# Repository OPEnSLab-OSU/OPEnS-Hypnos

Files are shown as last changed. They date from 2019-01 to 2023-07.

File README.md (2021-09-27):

# OpenS-Hypnos
Power Control Board for microcontroller projects, designed at OPEnS Lab OSU.

Go to [Hypnos Wiki](https://github.com/OPEnSLab-OSU/OPEnS-Lab-Home/wiki/Hypnos) for more info and build guide.

<p align="center">
    
 
</p>

### Pinout
Hypnos V3.3 Pinout

### Description
The OPEnS-Hypnos board is a simple, low-cost circuit board that can be attached to an Adafruit Feather M0 microcontroller and a DS3231 real-time clock breakout board to enable shutting off power to the microcontroller until a timed or sensed event wakes it up.
In the early time of development, the Feather needs to be shut down completely due to the inefficient  deep sleep firmware.
A circuit was designed to keep the state of the system, and a real-time clock can change the state and wake everything back up.
After Adafruit released new firmware for Feather M0 that allows microamp sleep current, complete shutdown of the Feather seem unnecessary.
However, during deep sleep, the 3v3 volt regulator is still providing power to other peripherals. 
MOSFET circuitry is introduced in HYPNOS to cut down power to peripherals. Additional RTC and microSD for accurate timekeeping and data logging.

* `Hypnos V2.x` Power + RTC + microSD with FeatherWing footprint. Allow control on 3.3V and VUSB rail. Using MOSFET circuit and Feather deep sleep
* `Hypnos V3.x` Upgraded from regular Hypnos. Can control one more rail of higher voltage (9-24V) at max 2.0 A continuous
* `Hypnos V3.3.lbr` Eagle library that has all of the components the Hypnos contains such as the push button, MOSFET footprints, Feather pinout, etc. 

### Specification
* Controlled 3v3 Rail (0.4 A continuous) and 5V Rail (0.5 A continuous from USB)
* [RTC DS3231](https://datasheets.maximintegrated.com/en/ds/DS3231.pdf) with TCXO
* Back up power CR1220 for RTC
* Micro SD slot

### Pinout for Feather M0
* RTC INTerrupt pin: GPIO 12
* 3.3V control pin: GPIO 5
* 5V control pin: GPIO 6
* SD chip select: GPIO 11

### How to use this board
<details>
<summary>Show more</summary>

### Important ! 3v3 RAIL ! 

Any I2C device behind [Adafruit I2C Multiplexer](https://www.adafruit.com/product/2717) does not need to be powered. We have tested the system with the Multiplexer turn off without the I2C line hanging.

Remember to power the 3.3Rail before initializing/communicating with uSD card, RTC, and I2C devices.

### Which rail to which?
<p align="center">

</p>

* **Feather Rail:** connects directly to your Feather. Anything connected to this rail will have their power constantly on and only turn off in **Shipment Mode**. Power Control will not work on this rail.

* **Sensor/Power Rail:** connects directly to your sensor board which you wish to turn the power on/off. The 5VUSB pin and 3V pin are controlled within the rail. Digital and Analog pins on this rail connect directly to the Feather. Extra 3V|5V with LEDs are for an external plug for prototyping.

### To control the power rails:



* **3v3 rail**: Set `PIN 5` of the Feather to **LOW** for closed circuit (conduct), otherwise, the pin is pulled HIGH for open circuit (not conduct).

* **5V rail**: Set `PIN 6` to **HIGH** for closed circuit (conduct), the PIN is pulled LOW for open circuit

* **+V rail**: This pin shares control with the 5V rail. Set `PIN 6` to **HIGH** for closed circuit (conduct), the PIN is pulled LOW for open circuit

**SD card:** Chip Select `PIN 11`, **required** 3.3Rail power, normal SPI communication

**RTC DS3231:** INT-errupt `PIN 12`, **required** 3.3Rail power, I2C pull up attached to 3.3Rail

**Note:** If you need a GPIO pin **AND** you are not using one of the 3V or 5V rails, you are able to free the GPIO pin for use by cutting the trace of the rail that is not used. 

### Shipment Mode
Short the `GND` and `EN` will turn off the 3.3V regulator temporarily. The male header + Jumper cap is a great combination. Once the jumper cap is removed, the Feather will boot up normally and resume operation.

</details>

### Note
* 5Vrail can go up to 1.2A if external 5V is connected directly to **Feather USB pin**
* The LEDs are low power (rated at 2mA instead of 20mA)
* I2C line pull up is attached to 3VRail

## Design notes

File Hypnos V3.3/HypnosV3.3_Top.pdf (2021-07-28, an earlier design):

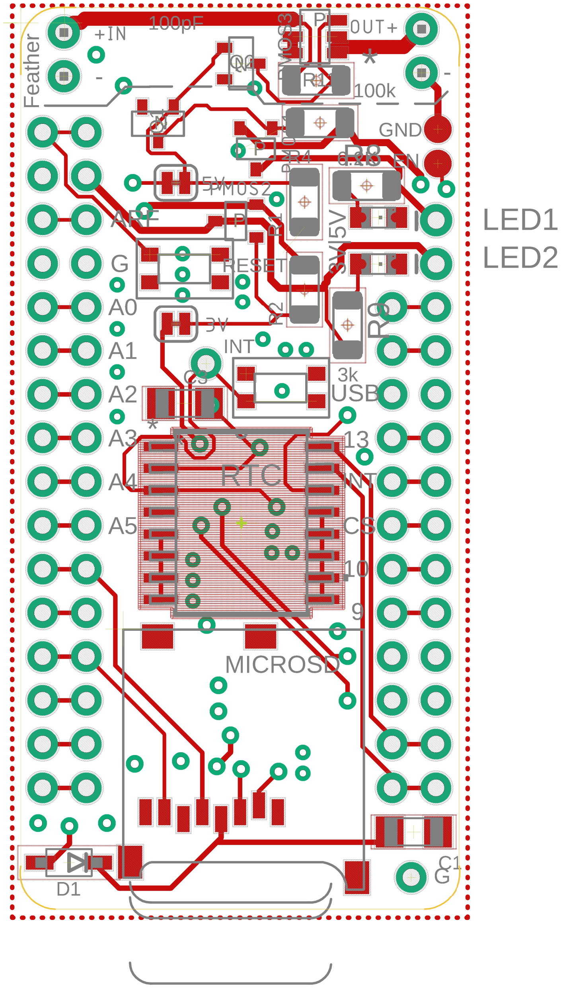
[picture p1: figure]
LED1 LED2

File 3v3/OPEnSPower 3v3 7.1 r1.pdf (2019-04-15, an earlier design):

OPEnS Power 3v3
Board Revision: 7.1
Document Revision: 1
Date: April 15, 2018
Author: Mitch Nelke

## Abstract

The OPEnS Power board is a simple, low cost circuit board that can be attached to an Adafruit Feather M0 microcontroller and a DS3231 real time clock breakout board to enable shutting off power to the microcontroller until a timed or sensed event wakes it up. The powered-down current draw of the system, minus any external circuits attached to the battery, is reduced to the order of 100 microAmps*. The board operates by applying two interrupt signals, one high-true and one low-true, to a flip flop integrated circuit to wake the device up. The flip flop latches the enable pin of the Feather's 3.3V regulator on or off. A digital output pin on the Feather is used to set the flip flop to latch the regulator off.

The OPEnS Power board is best suited for projects that require operating-time that are greatly shorter than their standby times. The lowest possible standby current achievable on the M0 without the OPEnS Power board is just under 1000 uA. By using the OPEnS Power board and assuming the on-time is far greater than the standby time, the battery life of the Feather M0 project can be increased by a factor of 10.

* Based on previous iterations of OPEnS Power. New iteration should be tested for exact value.

## Characteristics

Characteristic | Condition | Min | Max | Units
VCC | | TBD | 5.5 | V
CP Logic HIGH | VCC = 2.3-5.5V | 0.7 VCC | | V
CP Logic LOW | VCC = 2.3-5.5V | | 0.3 VCC | V
RTC_INT Logic HIGH | VCC = 4.2V | 0.7 VCC | | V
RTC_INT Logic LOW | VCC = 4.2V | | 0.3 VCC
INT_2 Logic HIGH | VCC = 4.2V | 2.5 | | V
INT_2 Logic LOW | VCC = 4.2V | | 1 | V
3v3 Reg EN Output Logic HIGH | VCC = 4.2V | TBD | | V
3v3 Reg EN Output Logic LOW | VCC = 4.2V | | TBD | V
Quiescent Current* | CP = LOW | | TBD | uA

*Does not include quiescent current from circuits using battery voltage on Feather M0 board.

## Theory of Operation

The OPEnS Power board uses a flip flop integrated circuit (IC) to turn on and off the 3.3V regulator on the Feather M0. The flip flop IC’s input pin D is permanently attached to the battery source. The logic state of the input is copied to the output, Q, when the clock pulse (CP) pin receives a rising edge from the M0. When CP receives a falling edge, nothing happens. The flip flop is powered from the battery and decoupled with a 100nF capacitor. The battery voltage pulls up the C-bar input through a 10k resistor. The C-bar input latches the Q output to ground whenever it is pulled low. The output remains low, ignoring any CP rising edges, until C-bar is pulled high.

The low-true interrupt meant to be connected to the DS3231 Real Time Clock’s (RTC) alarm output is directly tied to the C-bar pin. A second interrupt pin, INT_2, is high-true and is connected to the gate of an N-channel MOSFET. The MOSFET’s source pin is tied to ground and its drain pin is connected to C-bar so that a high voltage on the INT_2 signal will pull C-bar low. It is possible to read the state of C-bar through GPIO_READ by using input_pullup() in the Arduino IDE. A diode between this pin and C-bar protects the state of C-bar when the M0 is powered off.

The Q output is a low-true signal but the 3.3V Regulator’s Enable pin is high-true. The Q output is connected to the gate of a P-channel MOSFET to invert its logic. When Q is high, the source and drain of the MOSFET are essentially disconnected and the regulator enable pin is tied to ground. When Q is low, the source and drain are essentially shorted and the regulator enable pin receives the battery voltage through a 500 ohm resistor.

## Application

Connections
The application of the OPEnSPower 3.3V board is simple. An Adafruit Feather M0 board should be connected to the board. The default Read and CP pins are A4 and A5, respectively, if their jumpers are soldered. If their jumpers are not soldered, different pins can be chosen by soldering a wire to the flip-flop side of each jumper. The current draw of these signals is very small and so wire-wrap is acceptable.

A 3.7V LiPo battery should be connected to the Feather’s battery receptacle. The battery source is connected to the OPEnSPower board through the Feather’s BAT pin.

Finally, the RTC_INT pin should be connected to a low-true interrupt signal to wake up the device. This is usually the DS3231’s SQW pin, and an alarm should be set before shutting the

M0 down. A high-true interrupt signal can be connected to INT_2. Generally, such a device would have its own power supply and its ground should be connected to the M0 and OPEnSPower ground.

Software
Assuming the DS3231’s SQW pin is connected to the RTC_INT (“INT-“) pin of the OPEnSPower board, the control scheme is very simple.
1. Wake up the device if it is off by shorting the RTC_INT pin to ground.
2. Read volatile variables from Flash storage or wherever they are stored between power cycles.
3. Perform desired functions.
4. Save volatile variables to persistent storage location.
5. Reset RTC alarm and set new alarm time for the system to wake up.
6. Shut the device off by pulling GPIO_CP high on the M0.

## Schematic

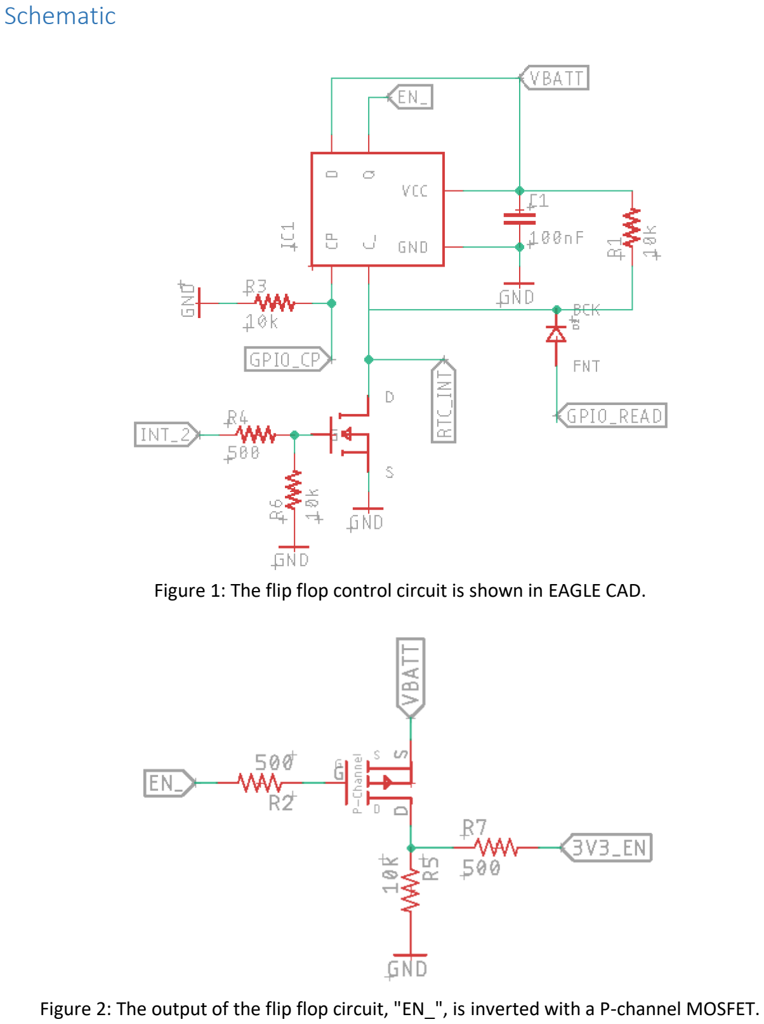
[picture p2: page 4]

Figure 1: The flip flop control circuit is shown in EAGLE CAD.

Figure 2: The output of the flip flop circuit, "EN_", is inverted with a P-channel MOSFET.

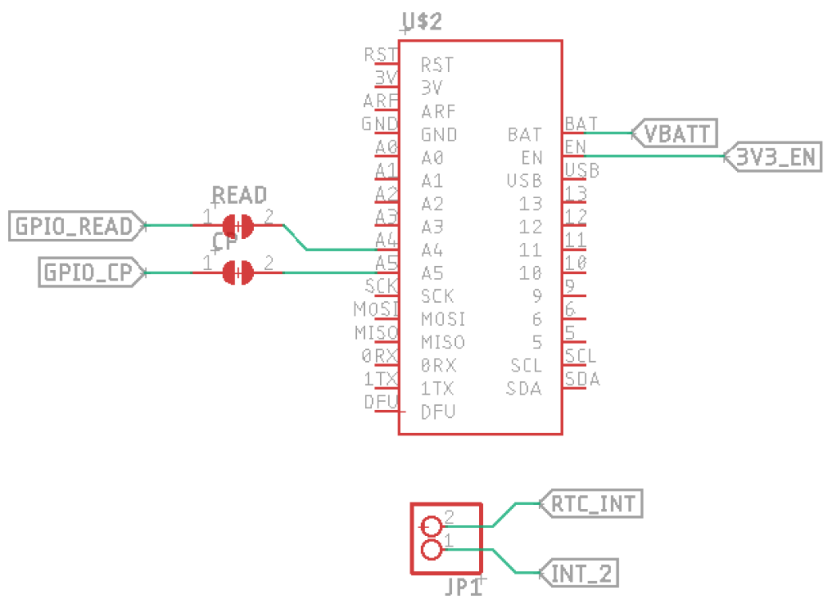
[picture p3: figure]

Figure 3: The Feather M0 is connected to READ, CP, VBATT, and 3v3_EN.

## Board Image From OSHPark

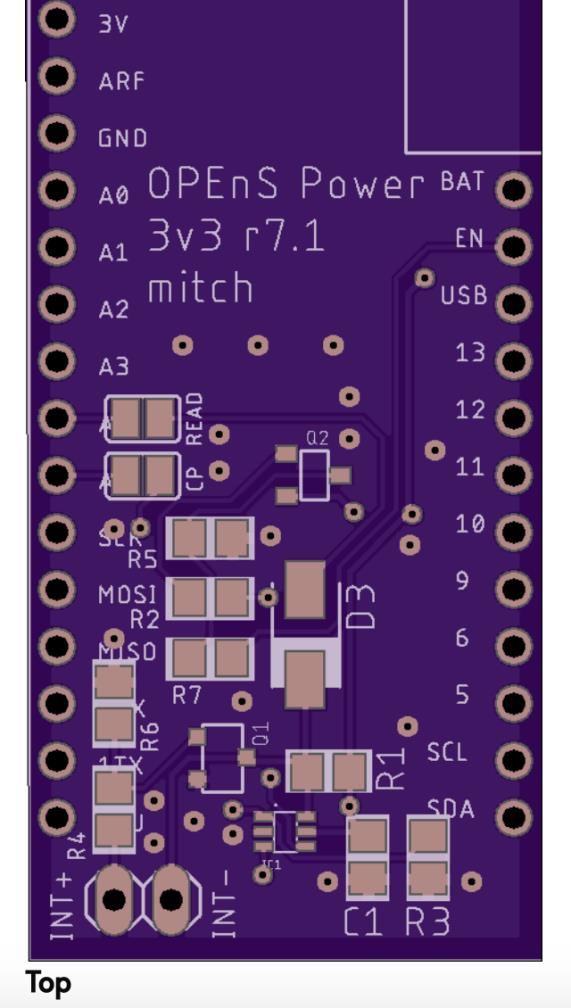
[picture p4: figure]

Figure 4: Top view of board after submitting to OSHPark for printing. Before operating, the CP and READ jumpers should be bridged with solder.

## Bill of Materials

Item | Value / ID | Footprint | Quantity | Board ID | Source
| | | | | (Hyperlink)
Resistor | 500 Ohm | 0805 | 3 | R2, R4, R7 | Digikey (https://www.digikey.com/product-detail/en/stackpole-electronics-inc/RNCP0805FTD499R/RNCP0805FTD499RCT-ND/2240560)
Resistor | 10 kOhm | 0805 | 4 | R1, R3, R5,
| | | | R6 | Digikey (https://www.digikey.com/product-detail/en/stackpole-electronics-inc/RNCF0805DTE10K0/RNCF0805DTE10K0CT-ND/2687083)
Capacitor | 100 nF | 0805 | 1 | C1 | Digikey (https://www.digikey.com/product-detail/en/yageo/CC0805KRX7R8BB104/311-1141-1-ND/303051)
MOSFET, N-
Channel | 2N7002-7-F | SOT-23-3 | 1 | Q1 | Digikey (https://www.digikey.com/product-detail/en/diodes-incorporated/2N7002-7-F/2N7002-FDICT-ND/717800)
MOSFET, P- Channel | SSM3J3228R | SOT-23-3 | 1 | Q2 | Digikey (https://www.digikey.com/product-detail/en/diodes-incorporated/BSS84-7-F/BSS84-FDICT-ND/717844)
Diode | APD340VRTR-
| G1 | DO-214AC | 1 | D1 | Digikey (https://www.digikey.com/product-detail/en/diodes-incorporated/APD340VRTR-G1/APD340VRTR-G1DICT-ND/5453146)
Flip Flop | NC7SZ175 | SC70/SC88 | 1 | IC1 | Digikey (https://www.digikey.com/product-detail/en/on-semiconductor/NC7SZ175P6X/NC7SZ175P6XCT-ND/673397)

## Future Development Suggestions

If a more efficient, simpler, or cheaper board is desired in the future, there are several routes that could be investigated. To start, the flip flop circuit could be redone or a new flip flop could be chosen so that the interrupt vectors act to pull the output of the flip flop high rather than low. This would remove the requirement of the inverting P-channel MOSFET circuit. For maximum efficiency, it would be desirable to fully analyze the Feather M0's 3.3V Regulator characteristics and adjust the interrupt vectors' rise and fall times and phase so that a flip flop IC is not necessary at all. It is worth noting that the internal leaking current of a LiPo battery is on the order of 100 uA, so reducing the quiescent current below this level has diminishing effects on overall battery life.

It should also be noted that this board does not disconnect the battery from the system during shutoff. There is a voltage divider on the Feather M0 feeding into an input pin to allow it to read the battery voltage, but the current draw of this divider is about 42 uA. The resistors can be removed to further reduce the system's standby current. The standby current of the 3.3V regulator when EN is low is on the order of 8 uA and so it is not useful to work around it.

## Reference Documents

Datasheet of Flip Flop: https://www.onsemi.com/pub/Collateral/NC7SZ175-D.PDF

Datasheet of Feather M0 3.3V Regulator: http://www.mouser.com/ds/2/146/SPX3819_DS_R200_082312-17072.pdf

Boards for OPEnS Lab are generally ordered from the 2-layer PCB Pool of OSHPark: https://oshpark.com/

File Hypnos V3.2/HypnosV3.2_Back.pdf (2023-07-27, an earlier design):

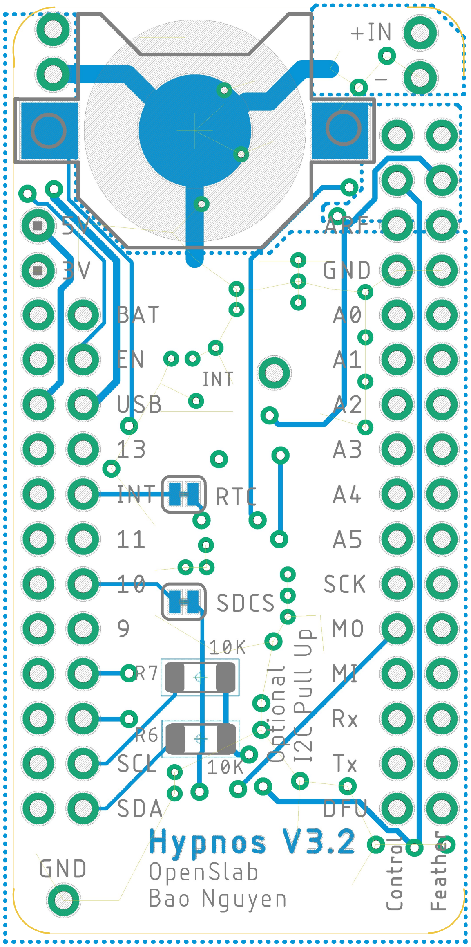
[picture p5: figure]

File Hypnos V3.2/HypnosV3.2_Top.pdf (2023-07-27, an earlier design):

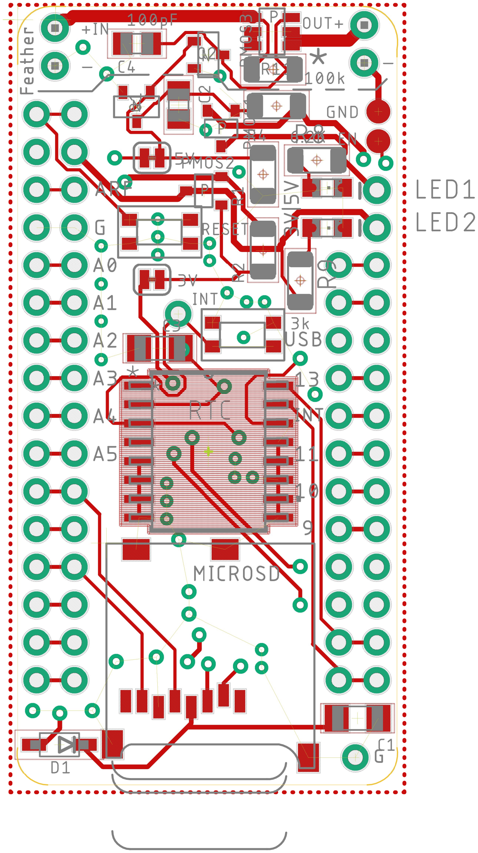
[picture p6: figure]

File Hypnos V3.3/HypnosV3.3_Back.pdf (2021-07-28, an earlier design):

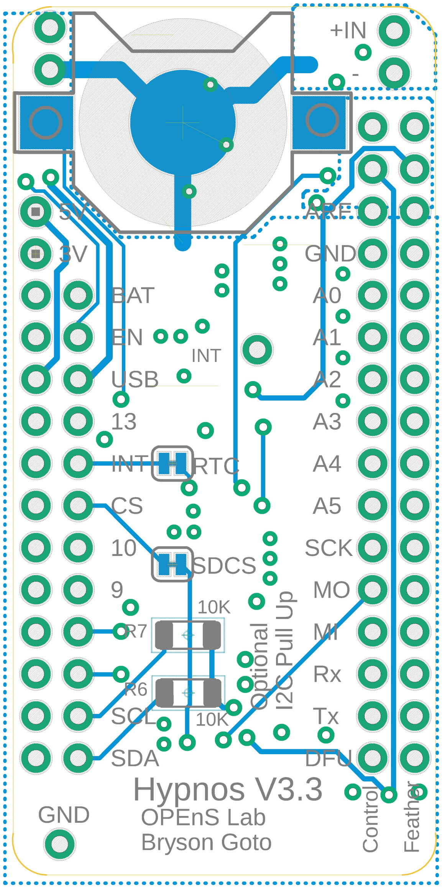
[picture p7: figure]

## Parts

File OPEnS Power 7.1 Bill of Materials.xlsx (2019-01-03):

Component | Board ID | Component ID | Source | Qty
Switching Regulator | IC2 | LM2575Sx-5.0/NOPBCT-ND | Digikey (https://www.digikey.com/product-detail/en/texas-instruments/LM2575SX-5.0-NOPB/LM2575SX-5.0-NOPBCT-ND/3440104) | 1
Barrel Jack | 12V_IN | CP-002BHPJCT-ND | Digikey (https://www.digikey.com/product-detail/en/cui-inc/PJ-002BH-SMT-TR/CP-002BHPJCT-ND/669694) | 1
Capacitor 100 uF | C12 | PCE3867CT-N | Digikey (https://www.digikey.com/product-detail/en/panasonic-electronic-components/EEE-1AA101WR/PCE3867CT-ND/766243) | 1
Capacitor 470 uF | C13 | 493-2181-1-ND | Digikey (https://www.digikey.com/product-detail/en/nichicon/UWT1C471MNL1GS/493-2181-1-ND/590156) | 1
Capacitor 100 nF | C1 | 1276-1007-1-ND | Digikey (https://www.digikey.com/product-detail/en/samsung-electro-mechanics/CL21F104ZBCNNNC/1276-1007-1-ND/3889093) | 1
Inductor 470 uH | L1 | 732-1690-1-ND | Digikey (https://www.digikey.com/product-detail/en/wurth-electronics-inc/744770247/732-1690-1-ND/1994270) | 1
Diode General Thru | D4 | 641-1310-1-ND | Digikey (https://www.digikey.com/product-detail/en/comchip-technology/1N4001-G/641-1310-1-ND/1979675) | 1
Resistor 10k | R3, R4 | RR12P10.0KDCT-ND | Digikey (https://www.digikey.com/product-detail/en/stackpole-electronics-inc/CF18JT10K0/CF18JT10K0CT-ND/2022766) | 2
Resistor 130k | R1 | 311-130KCRCT-ND | Digikey (https://www.digikey.com/product-detail/en/yageo/RC0805FR-07130KL/311-130KCRCT-ND/730537) | 1
Resistor 300k | R2 | RR12P300KDCT-ND | Digikey (https://www.digikey.com/product-detail/en/susumu/RR1220P-304-D/RR12P300KDCT-ND/432889) | 1
Diode General SMD | D2, D3 | S1A-FDICT-ND | Digikey (https://www.digikey.com/product-detail/en/diodes-incorporated/S1A-13-F/S1A-FDICT-ND/750031) | 2
Flip Flop | IC1 | 296-16998-1-ND | Digikey (https://www.digikey.com/product-detail/en/texas-instruments/SN74LVC1G175DCKR/296-16998-1-ND/656525) | 1
MOSFET N-Type | Q1 | 2N7002-TPMSCT-ND | Digikey (https://www.digikey.com/product-detail/en/micro-commercial-co/2N7002-TP/2N7002-TPMSCT-ND/1960099) | 1
Diode - Zener 5.1V | D1 | BZD27C4V3P-E3-08GICT-ND | Digikey (https://www.digikey.com/product-detail/en/vishay-semiconductor-diodes-division/BZD27C4V3P-E3-08/BZD27C4V3P-E3-08GICT-ND/6680647) | 1

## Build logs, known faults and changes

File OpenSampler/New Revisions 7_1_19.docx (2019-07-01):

Change with James:

- Replace RTC capacitor with battery since charging capacitor would take sometimes, as well as the voltage are only usable in a certain range.

Charging with 4.2- 0.7 = 3.5 volt is still higher than the voltage the RTC can handle which is 3V.

- Utilized Voltage Divider on 2nd Inverter node and V_Latch node to determine NMOS resistance value for proper current.

Change by Bao:

- Reposition the side rail so it fit on the breadboard - Multiple of 2.54mm spacing

- Replace test pins with continuous header holes

- Resize and rearrange printed letters so they would print nicely

- Add letters for test pins

- Rewire signal rail and power rail for easy installation

- Move LED from bottom layer to front

Suggested change from Bao:

- Remove 1nF capacitor due protect the RTC. Current spike is allowed for the RTC INT => can blow the RTC

- The board when overrided to stay awake, the latch will pulled to GND. The shutdown pin is only have 1 resistor and 1 diode away from a feather pin.

This will cause over current sink from the feather pin if it tries to sent shutdown signal.

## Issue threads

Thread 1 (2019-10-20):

Measuring SD card current

kamocat, 2019-10-20:
Currently there isn't a way of measuring the current consumption of the SD card separate from the reset of the system.
A simple 1-ohm high-side sense resistor would allow measurement, requiring minimal board space. Optionally, this signal could be wired back and monitored by the Feather.

**Benefits of measuring the SD card current:**
* Compare current draw of different SD cards (brand, capacity, age, etc)
* Ensure that a write operation is complete before shutting off power (to avoid data corruption)
* Compare power consumption of cached vs uncached writes

nguyenb5, 2019-10-29:
The issue has been viewed. What do you think is the best way to read the voltage drop across the resistor, just an analog pin? Do you think that the drop through the MOSfet also effect the reading?

kamocat, 2019-10-31:
Maybe you're right, that no-one is going to measure the current from the Feather.
I found a different issue that complicates this, though. My SD card seems to be feeding power back into the 3.3V rail through the SPI bus. I haven't tried a current test (because I don't wish to break the SD card), but it's enough to turn on the LED.
I think it's getting the power either from MOSI or SCK, because setting CS low didn't completely fix it. Maybe a schottkey diode would do it?
I guess the simple answer is that if I want the feather to sleep, I need to disable all the output drivers first.

nguyenb5, 2019-11-01:
Did you have the SD card inserted then started the SPI protocol? I am trying to replicate the issue on my end for troubleshooting.

kamocat, 2019-11-13:
Closing this issue. I changed my mind about the current consumption, I can put a sense resistor on the 3v3 rail if I want.

Closed 2019-11-13.

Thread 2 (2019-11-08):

Current leak from MISO, MOSI, CS ?

nguyenb5, 2019-11-08:
When the SD card is initialized and the 3V power rail is disconnected, the 3VRAIL seem to still turn on (LED lit up).

Need to probe voltage at MISO, MOSI, CLK, SD to check if there is any current flowing backward to the 3Vrail when the 3V control pin is not activated.

Issue seen from Sitka+ SapFlow.

kamocat, 2019-11-13:
Yes, you need to start the SPI protocol, or at configure some of those pins as outputs.

kamocat, 2019-11-13:
Additionally, I would recommend moving the I2C pull-ups to the unswitched 3V3 rail, as they also are dimly powering the LED when pull-ups on the Feather are enabled. This would put them on the same rail as the RTC.

nguyenb5, 2019-11-14:
Hi Marshal, I read over your message but did not understand well the issue with the I2C Pull-up resistors.

I have not talked to the Loom team but please let us know if you found a way to fix this in software. From Max's testing, the current is leaking from all of the SPI pin including CS. I will start implementing the diode fix to future update, but I do want to sit down and have a chat with you for the board schematic before we purchase anything.

kamocat, 2019-11-14:
My bad. I misread the schematic, and thought the pullups connected to 3VRail, not 3V3.

kamocat, 2019-11-14:
Setting the pins as inputs seems to work pretty well.
Just make sure you don't set pin 22 as an output.
Here's an example sketch.
https://gist.github.com/kamocat/b4cf9f0ccbd765f78a6d7390d2da2fe8

nguyenb5, 2019-11-21:
Hi Marshal,

Where you able to use this code with Loom?

kamocat, 2019-11-23:
I haven't tried it with Loom, but I don't see any reason why it wouldn't work.

nguyenb5, 2020-01-18:
[Updates](https://github.com/OPEnSLab-OSU/OPEnS-Lab-Home/wiki/Hypnos-Updates). A diode has been place between 3v3Rail and the VCC of the SDcard that reduce leakage current down to 1.9uA.

Diode: [SM5817PL-TP](https://www.digikey.com/product-detail/en/micro-commercial-co/SM5817PL-TP/SM5817PL-TPMSCT-ND/1793410)

Closed 2020-01-18.

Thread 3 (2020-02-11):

I2C line broke for non-powered external sensor

nguyenb5, 2020-02-11:
With the code test for the RTC DS3231, the I2C communication would fail if there is external I2C sensor that connected to SDA and SCL without being power (disconnected Vcc and GND).

nguyenb5, 2020-02-12:
Phantom Power : https://forum.arduino.cc/index.php?topic=642971.0

udellc, 2020-02-13:
Is there a way to disconnect only the VCC line to the sensor, but keeping it grounded? Would that fix the issue?

udellc, 2020-02-17:
It looks like isolating the i2c bus will be necessary. This one is an updated version of the one recommended on the discussion board posted above:
http://www.ti.com/product/TCA4311A
I think we may need to make a new version of our Loom i2c shield, which includes an option to populate the TCA9548 i2c MUX but also with the TCA4311A buffer on the shield's i2c input.
The shield should also include an i2c pass through after the buffer, for being able to use isolated i2c devices without the MUX if desired.

nguyenb5, 2020-02-18:
This issue is not resolved yet. The buffer require some more space that the current Hypnos V2 does not have. Requested feature will be postponed to later version.

nguyenb5, 2020-03-24:
For now, the system is still usable if the all of the I2C devices are powered before communicating with the RTC. The I2C Multiplexer can be not powered, and system will still work.

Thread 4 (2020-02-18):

Current leak from I2C line

nguyenb5, 2020-02-18:
[Hypnos V2.zip](https://github.com/OPEnSLab-OSU/OPEnS-Hypnos/files/4216852/Hypnos.V2.zip)
The current I2C line is pulled up to +3V. Sensors which share the pin will use the power from the I2C line when they are being shut off. For the MMA8451 board, I was getting leakage of 170uA for SCL and 70uA for SDA when the device is off and no communication.

kamocat, 2020-02-23:
That's strange. I thought the pull-ups were tied to the switched 3V3 rail.

nguyenb5, 2020-03-01:
not in the current Hypnos V2. We fixed it in Hypnos V2.1.

Closed 2020-03-24.

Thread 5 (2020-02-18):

Periodic Sleep/Wake Hangs After ~20min

prototypicalpro, 2020-02-18:
I am experience hanging when using the Hypons board with the Loom Sleep example (https://github.com/OPEnSLab-OSU/Loom/tree/master/examples/Lab%20Examples/Hypnos_SD_Sleep). I have found that consistently after about 20 minutes of continuous sleep/wakeup operation, the board will freeze just after waking up, and will remain unresponsive until it is reset.

I am using an Adafruit Feather M0 WiFi with the new and old hypnos versions. I used the same RTC battery for both, which measured 2.913V.  Interestingly, an RTC breakout with an adalogger did not experience the same symptoms, despite also using sleep functionality (The RTC battery on the breakout measured slightly higher at 3.012V, but seemed too little of a difference to cause issues). Frustratingly, I also found this issue only happens when using sleep functionality: in other words I am unable to reproduce the issue after removing the "Loom.SleepManager().sleep()" line.

prototypicalpro, 2020-02-18:
All of a sudden I'm having issues replicating the problem: I ran the same setup of both new and old hypnos over the weekend with no issue. Since my previous tests were Tuesday-Thursday, @udellc suggested the issue might be related to the RTC being set to that time, however I tested setting RTC to last Thursday and was still unable to replicate the issue.

I'm stumped as to what to test next. Any ideas @nguyenb5 ?

nguyenb5, 2020-07-03:
I still not yet heard any other report about the board freeze from walking up. There will be another batch for Hypnos V3.2 that have been tested by two other projects. Please let me know if this happen again. For now, I think you should wake up, turn on the 3V rail and delay for at least 10ms for the I2C pull up.

udellc, 2020-07-03:
FYI

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

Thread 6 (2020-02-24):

Finalize Board for Build Party?

udellc, 2020-02-24:
Are these issues for V2 still a problem? What needs to be fixed to finalize the design so we can have the next build party?
Thanks,
Chet

nguyenb5, 2020-04-06:
Hi Dr.Chet, changes has been implemented for the V2 and V3. Ready for testing

Closed 2020-04-17.

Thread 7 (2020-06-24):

Always connect 3.3V and 5V control solder pad

nguyenb5, 2020-06-24:
Currently, to have the control power for the 3.3V rail and 5V rail, user would have to solder bridge pads. Since this is a normal feature, it should be activated out of the box.

Newer version of the PCB should have this to reduce solder time and chances that one might forget.

nguyenb5, 2020-07-03:
Fixed in Hypnos V3.2 and V2.2

Closed 2020-07-03.

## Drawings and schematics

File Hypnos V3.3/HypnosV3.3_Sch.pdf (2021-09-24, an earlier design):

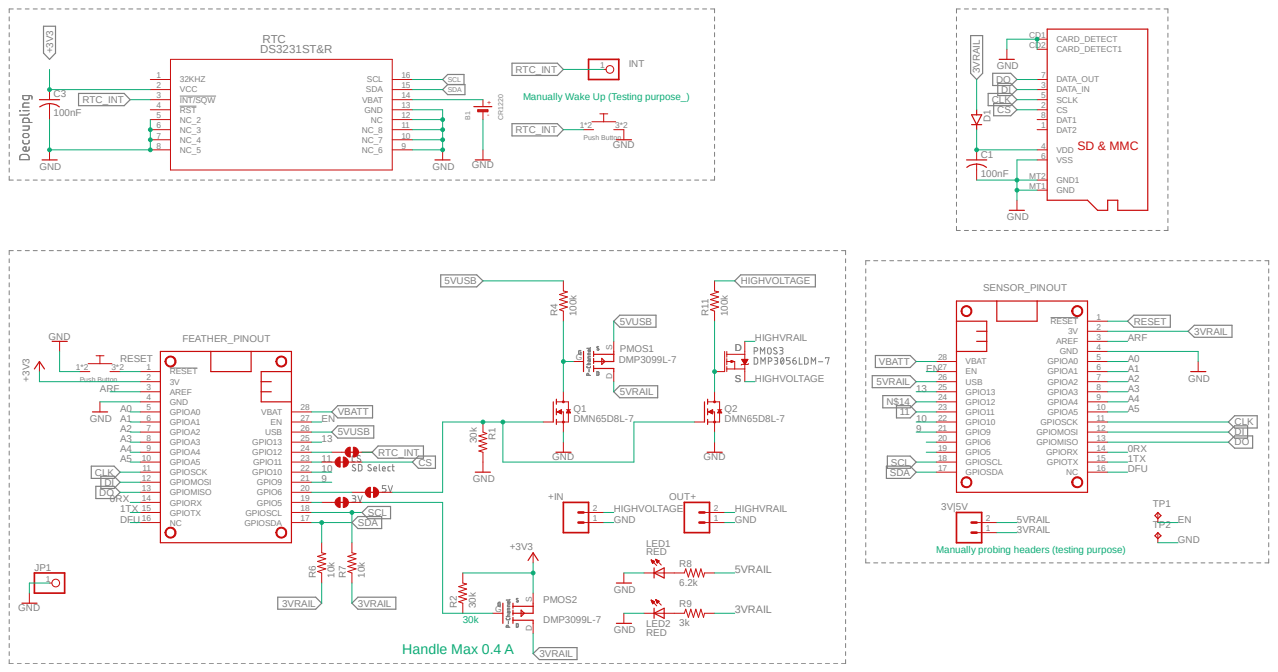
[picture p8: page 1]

SCL SDA ⁺³V³
GND GND 30k GND ³⁰k

Manually probing headers (testing purpose) 30k Handle Max 0.4 A

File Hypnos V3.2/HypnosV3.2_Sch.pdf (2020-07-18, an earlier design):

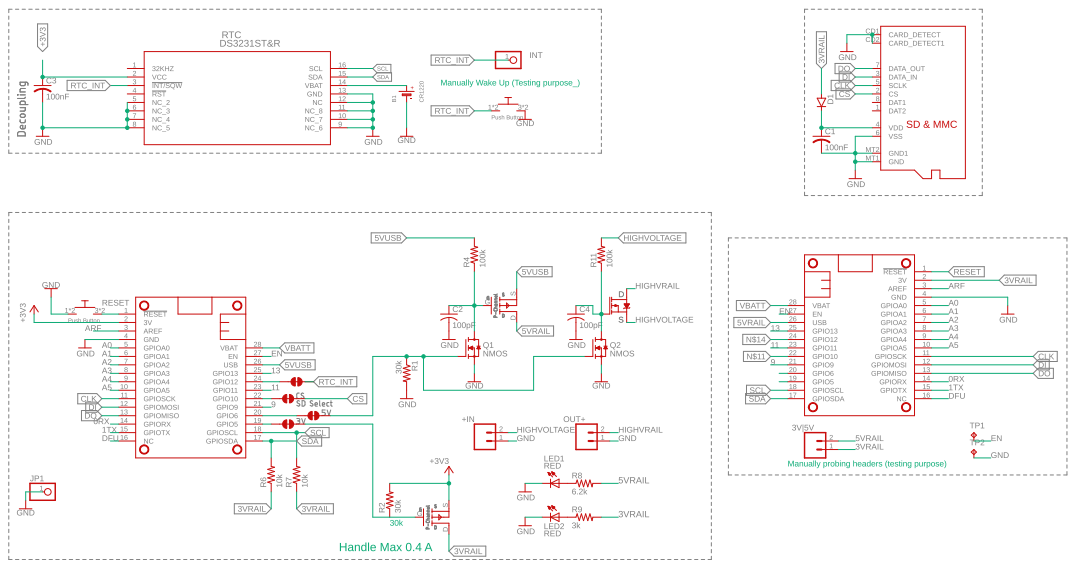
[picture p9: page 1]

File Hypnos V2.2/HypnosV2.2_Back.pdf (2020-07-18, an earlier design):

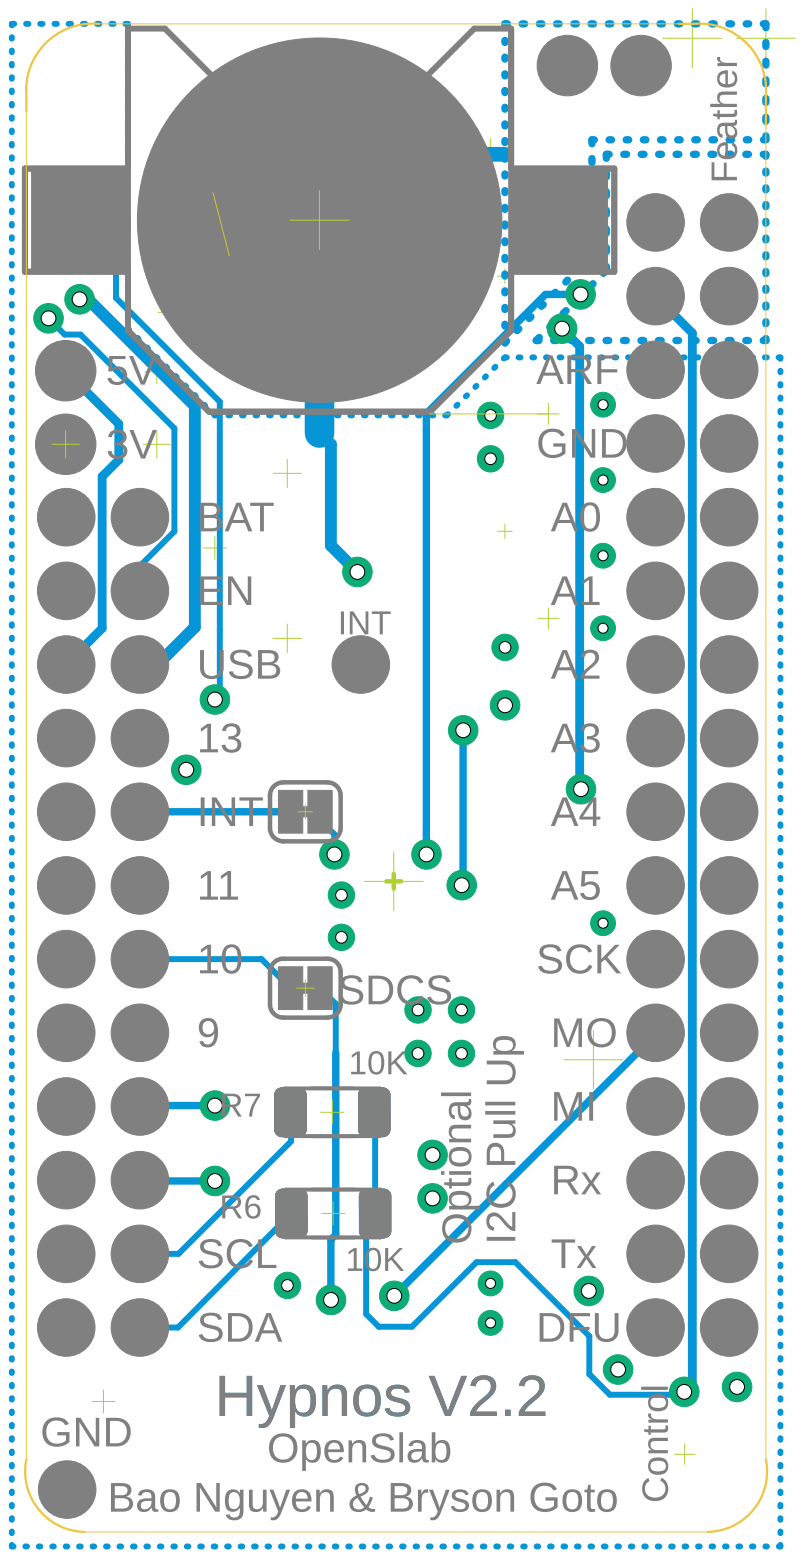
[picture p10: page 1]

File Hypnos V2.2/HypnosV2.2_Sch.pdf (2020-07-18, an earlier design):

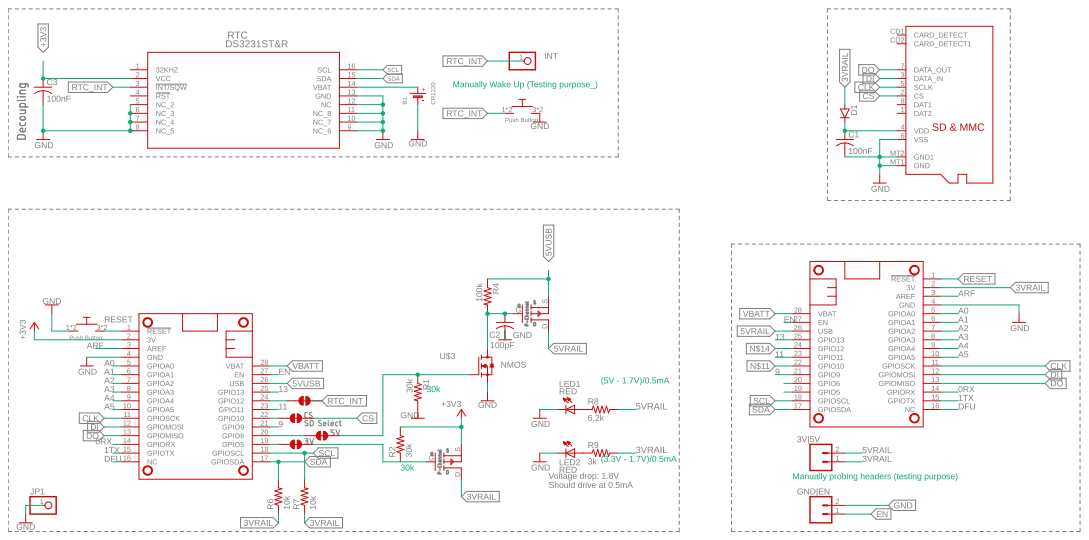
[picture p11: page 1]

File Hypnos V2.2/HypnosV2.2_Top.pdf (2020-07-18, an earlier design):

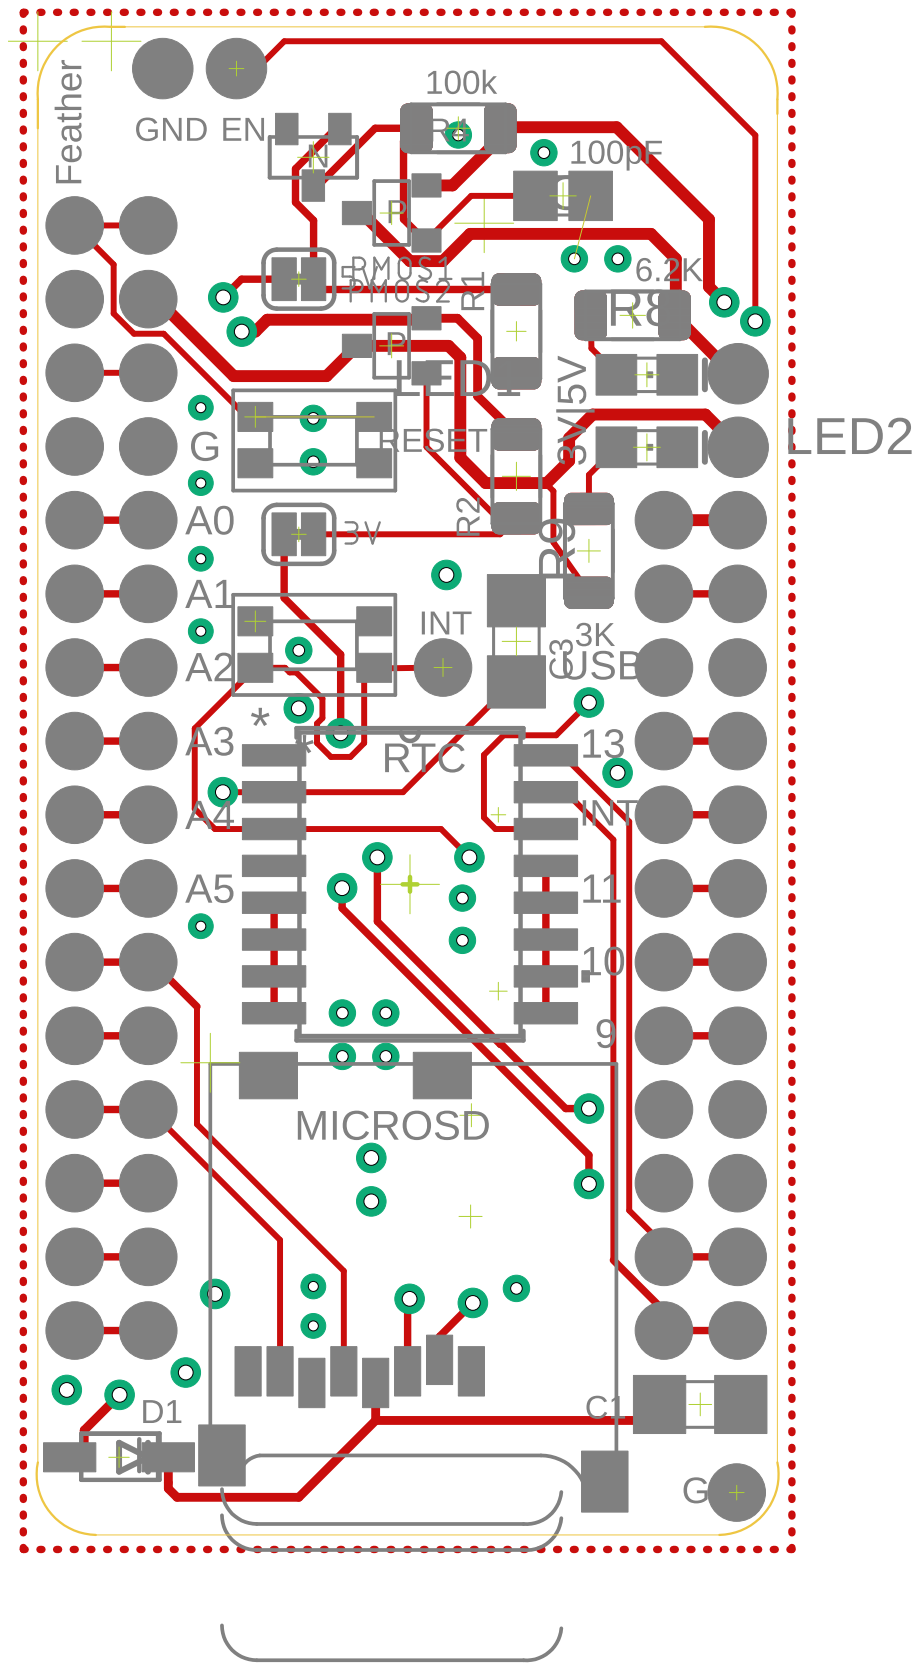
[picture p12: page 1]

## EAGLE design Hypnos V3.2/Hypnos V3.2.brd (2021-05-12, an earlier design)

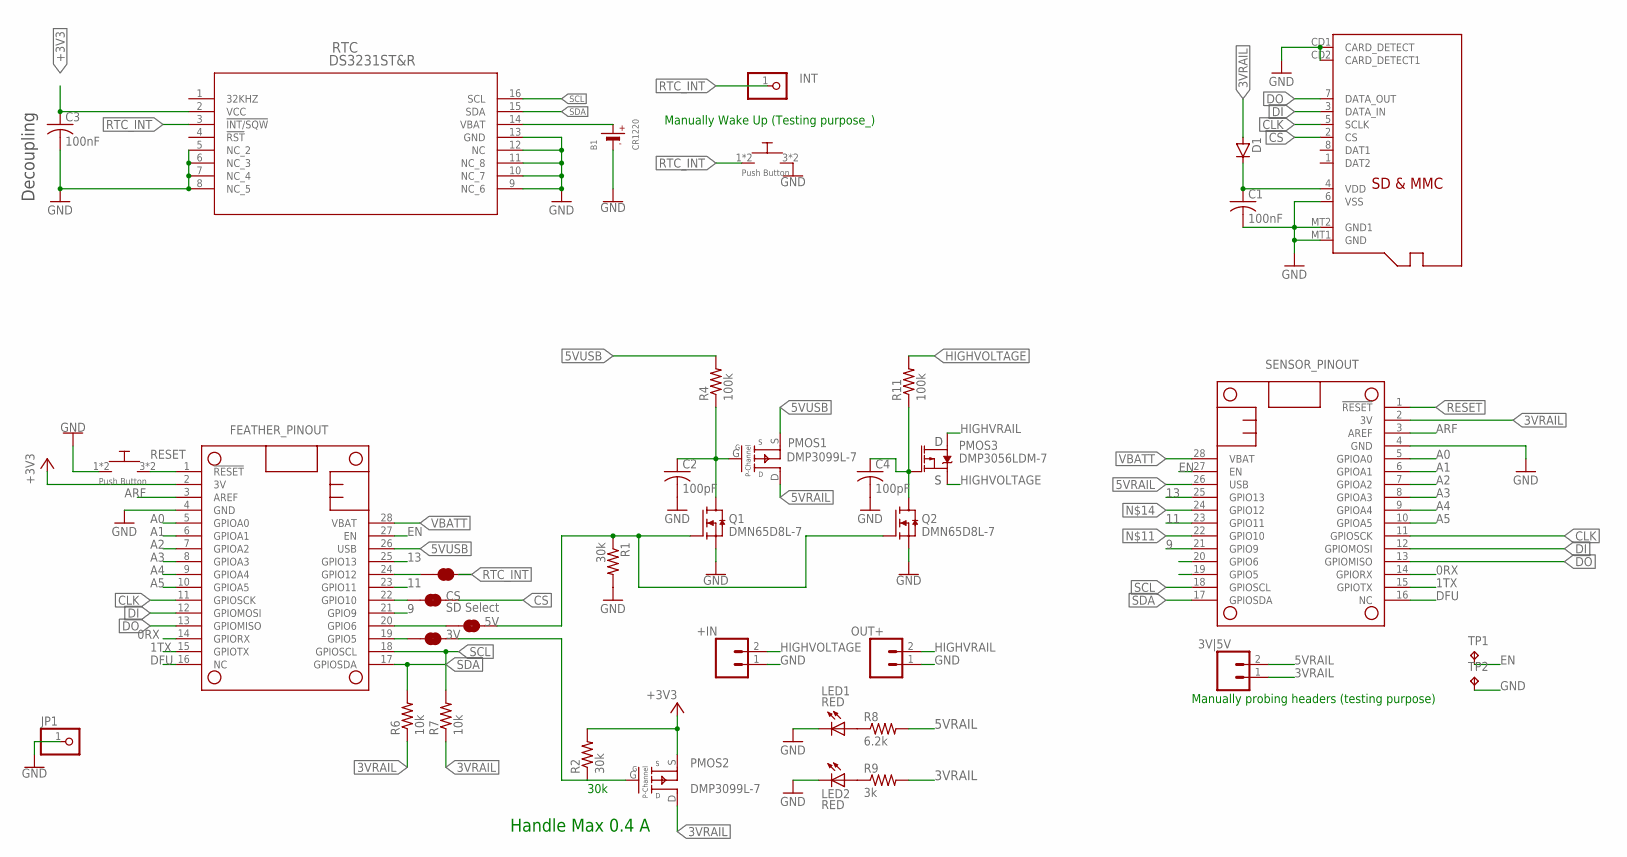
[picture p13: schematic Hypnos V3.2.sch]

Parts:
3V, 5V: JUMPER-SMT_2_NC_TRACE_SILK; SMT-JUMPER_2_NC_TRACE_SILK
3V|5V: CONN_021X02_NO_SILK; 1X02_NO_SILK
+IN: HIGHV-IN; 1X02_NO_SILK
B1: CR1220
C1, C3: 100nF; C1206
C2, C4: 100pF; C0805
CS: SD Select; SMT-JUMPER_2_NC_TRACE_SILK
D1: D-SOD123; SOD123
FEATHERWING: SENSOR_PINOUT; FEATHERWING
INT: PINHD-1X1CB; 1X01-CLEANBIG
JP1: PINHD-1X1CB; 1X01-CLEANBIG
LED1, LED2: RED; CHIPLED_0805
MICROSD: MICROSD
MS2: FEATHER_PINOUT; FEATHERWING
OUT+: HIGHV-OUT; 1X02_NO_SILK
PMOS1, PMOS2: DMP3099L-7; SOT-23-3
PMOS3: DMP3056LDM-7; SOT23-6
Q1, Q2: DMN65D8L-7; SOT23-S
R1, R2: 30k; RES_1206
R4, R11: 100k; RES_1206
R6, R7: 10k; RES_1206
R8: 6.2k; RES_1206
R9: 3k; RES_1206
RTC: DS3231ST&R; 21-0042B_16
RTC_INT: JUMPER-SMT_2_NC_TRACE_SILK; SMT-JUMPER_2_NC_TRACE_SILK
TP1, TP2: TPTP16R; TP16R
U$1, U$2: PUSH_BUTTON; PUSHBUTTON_SMD

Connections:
0RX: FEATHERWING.14 (GPIORX), MS2.14 (GPIORX)
1TX: FEATHERWING.15 (GPIOTX), MS2.15 (GPIOTX)
3VRAIL: 3V|5V.1, D1.2 (A), FEATHERWING.2 (3V), PMOS2.D, R6.1, R7.1, R9.2
5VRAIL: 3V|5V.2, FEATHERWING.26 (USB), PMOS1.D, R8.2
5VUSB: MS2.26 (USB), PMOS1.S, R4.2
9: FEATHERWING.21 (GPIO9), MS2.21 (GPIO9)
11: FEATHERWING.23 (GPIO11), MS2.23 (GPIO11)
13: FEATHERWING.25 (GPIO13), MS2.25 (GPIO13)
+3V3: C3.1, MS2.2 (3V), PMOS2.S, R2.2, RTC.2 (VCC)
A0: FEATHERWING.5 (GPIOA0), MS2.5 (GPIOA0)
A1: FEATHERWING.6 (GPIOA1), MS2.6 (GPIOA1)
A2: FEATHERWING.7 (GPIOA2), MS2.7 (GPIOA2)
A3: FEATHERWING.8 (GPIOA3), MS2.8 (GPIOA3)
A4: FEATHERWING.9 (GPIOA4), MS2.9 (GPIOA4)
A5: FEATHERWING.10 (GPIOA5), MS2.10 (GPIOA5)
ARF: FEATHERWING.3 (AREF), MS2.3 (AREF)
CLK: FEATHERWING.11 (GPIOSCK), MICROSD.5 (SCLK), MS2.11 (GPIOSCK)
CS: CS.2, MICROSD.2 (CS)
DFU: FEATHERWING.16 (NC), MS2.16 (NC)
DI: FEATHERWING.12 (GPIOMOSI), MICROSD.3 (DATA_IN), MS2.12 (GPIOMOSI)
DO: FEATHERWING.13 (GPIOMISO), MICROSD.7 (DATA_OUT), MS2.13 (GPIOMISO)
EN: FEATHERWING.27 (EN), MS2.27 (EN), TP1.TP
GND: +IN.1, B1.-, C1.2, C2.2, C3.2, C4.2, FEATHERWING.4 (GND), JP1.1, LED1.C, LED2.C, MICROSD.6 (VSS), MICROSD.CD1 (CARD_DETECT), MICROSD.CD2 (CARD_DETECT1), MICROSD.MT1 (GND), MICROSD.MT2 (GND1), MS2.4 (GND), OUT+.1, Q1.2 (S), Q2.2 (S), R1.2, RTC.5 (NC_2), RTC.6 (NC_3), RTC.7 (NC_4), RTC.8 (NC_5), RTC.9 (NC_6), RTC.10 (NC_7), RTC.11 (NC_8), RTC.12 (NC), RTC.13 (GND), TP2.TP, U$1.1, U$1.2, U$2.3, U$2.4
HIGHVOLTAGE: +IN.2, PMOS3.4 (S), R11.2
HIGHVRAIL: OUT+.2, PMOS3.1 (D), PMOS3.2 (D), PMOS3.5 (D), PMOS3.6 (D)
unnamed: 5V.1, MS2.20 (GPIO6)
unnamed: B1.+$1 (+), RTC.14 (VBAT)
unnamed: 3V.1, MS2.19 (GPIO5)
unnamed: 5V.2, Q1.1 (G), Q2.1 (G), R1.1
unnamed: 3V.2, PMOS2.G, R2.1
unnamed: C2.1, PMOS1.G, Q1.3 (D), R4.1
unnamed: CS.1, FEATHERWING.22 (GPIO10), MS2.22 (GPIO10)
unnamed: LED1.A, R8.1
unnamed: LED2.A, R9.1
unnamed: FEATHERWING.24 (GPIO12), MS2.24 (GPIO12), RTC_INT.1
unnamed: C4.1, PMOS3.3 (G), Q2.3 (D), R11.1
RESET: FEATHERWING.1 (!RESET), MS2.1 (!RESET), U$1.3, U$1.4
RTC_INT: INT.1, RTC.3 (!INT/SQW), RTC_INT.2, U$2.1, U$2.2
SCL: FEATHERWING.18 (GPIOSCL), MS2.18 (GPIOSCL), R7.2, RTC.16 (SCL)
SDA: FEATHERWING.17 (GPIOSDA), MS2.17 (GPIOSDA), R6.2, RTC.15 (SDA)
VBATT: FEATHERWING.28 (VBAT), MS2.28 (VBAT)
VDD: C1.1, D1.1 (C), MICROSD.4 (VDD)

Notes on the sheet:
Decoupling
Manually Wake Up (Testing purpose_)
Manually probing headers (testing purpose)
30k
Handle Max 0.4 A

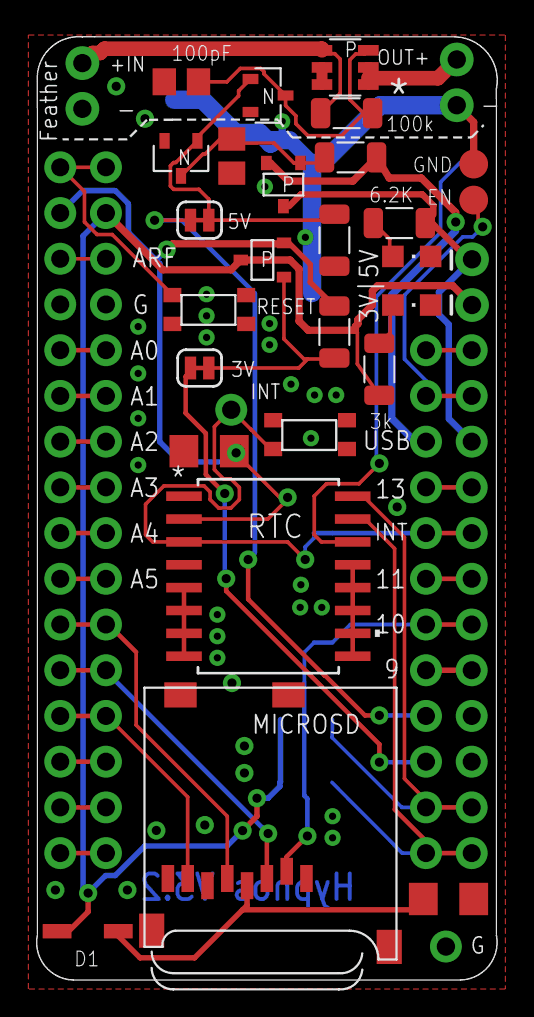
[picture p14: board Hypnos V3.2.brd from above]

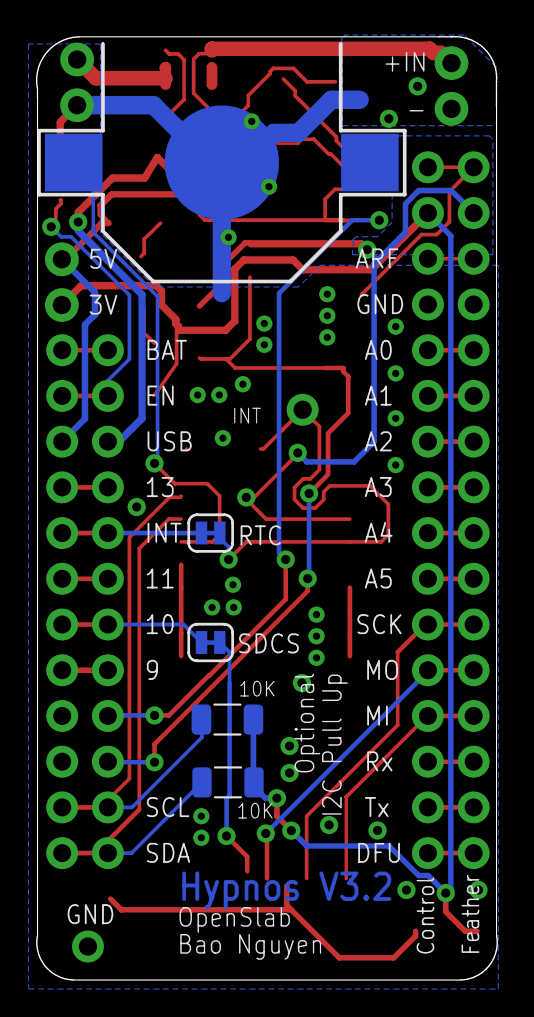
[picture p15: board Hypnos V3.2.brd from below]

Board: 2 copper layers, 25.6 x 52.4 mm, 38 parts (6 on the bottom side), 42 nets.

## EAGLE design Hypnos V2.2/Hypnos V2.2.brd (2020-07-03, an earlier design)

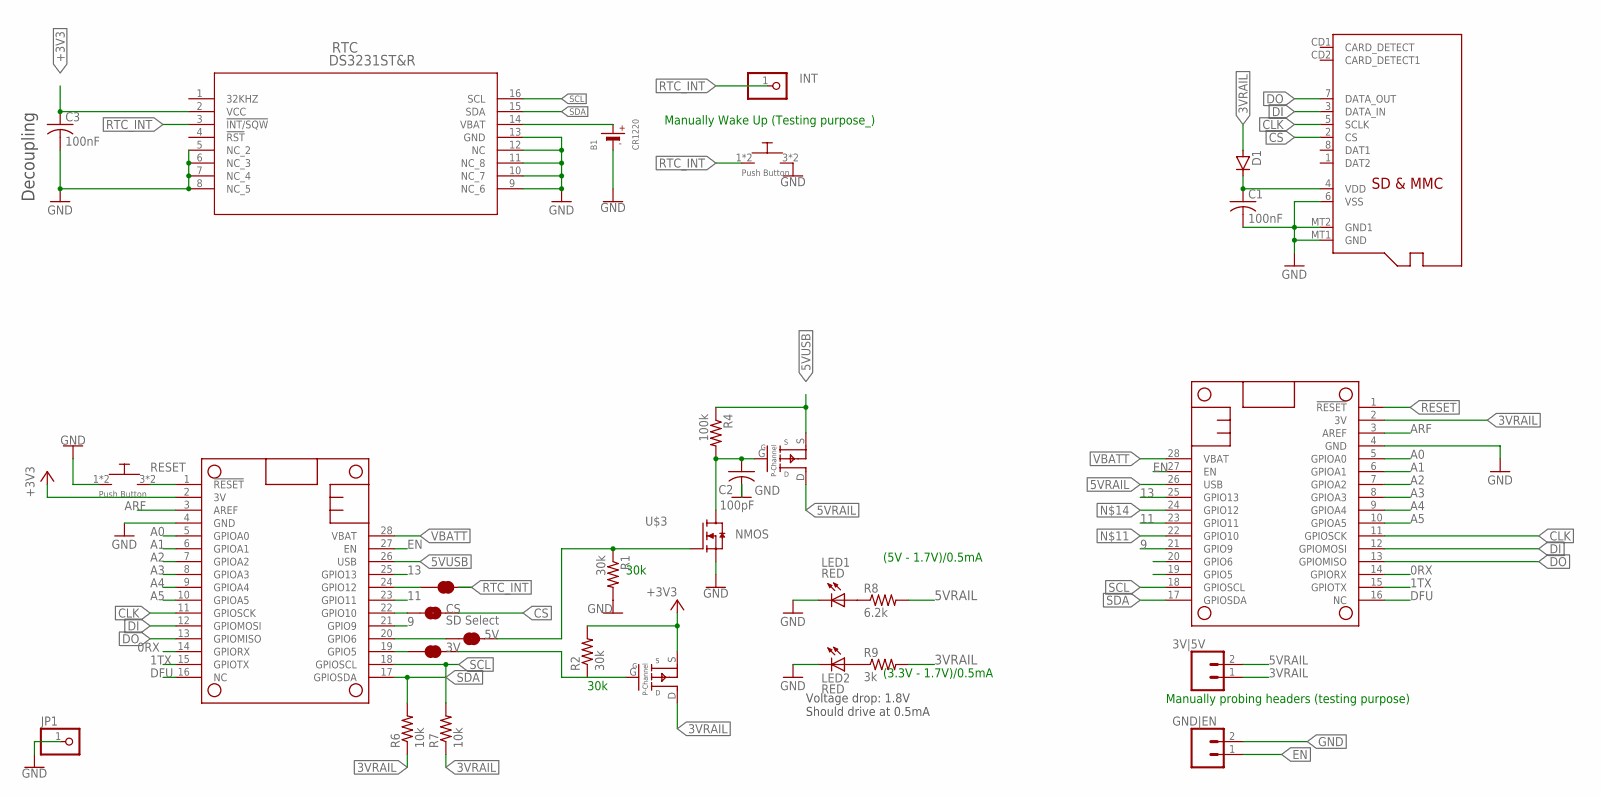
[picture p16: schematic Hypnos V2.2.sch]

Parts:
3V, 5V: JUMPER-SMT_2_NC_TRACE_SILK; SMT-JUMPER_2_NC_TRACE_SILK
3V|5V: CONN_021X02_NO_SILK; 1X02_NO_SILK
B1: CR1220
C1, C3: 100nF; C1206
C2: 100pF; C0805
CS: SD Select; SMT-JUMPER_2_NC_TRACE_SILK
D1: D-SOD123; SOD123
GND|EN: CONN_021X02_NO_SILK; 1X02_NO_SILK
INT: PINHD-1X1CB; 1X01-CLEANBIG
JP1: PINHD-1X1CB; 1X01-CLEANBIG
LED1, LED2: RED; CHIPLED_0805
MICROSD: MICROSD
MS1, MS2: FEATHERWING
PMOS1, PMOS2: SSM3J3228R; SOT-23-3
R1, R2: 30k; RES_1206
R4: 100k; RES_1206
R6, R7: 10k; RES_1206
R8: 6.2k; RES_1206
R9: 3k; RES_1206
RTC: DS3231ST&R; 21-0042B_16
RTC_INT: JUMPER-SMT_2_NC_TRACE_SILK; SMT-JUMPER_2_NC_TRACE_SILK
U$1, U$2: PUSH_BUTTON; PUSHBUTTON_SMD
U$3: NMOS; SOT23-S

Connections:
0RX: MS1.14 (GPIORX), MS2.14 (GPIORX)
1TX: MS1.15 (GPIOTX), MS2.15 (GPIOTX)
3VRAIL: 3V|5V.1, D1.2 (A), MS1.2 (3V), PMOS2.D, R6.1, R7.1, R9.2
5V: 3V.2, PMOS2.G, R2.1
5VRAIL: 3V|5V.2, MS1.26 (USB), PMOS1.D, R8.2
5VUSB: MS2.26 (USB), PMOS1.S, R4.1
9: MS1.21 (GPIO9), MS2.21 (GPIO9)
11: MS1.23 (GPIO11), MS2.23 (GPIO11)
13: MS1.25 (GPIO13), MS2.25 (GPIO13)
+3V3: C3.1, MS2.2 (3V), PMOS2.S, R2.2, RTC.2 (VCC)
A0: MS1.5 (GPIOA0), MS2.5 (GPIOA0)
A1: MS1.6 (GPIOA1), MS2.6 (GPIOA1)
A2: MS1.7 (GPIOA2), MS2.7 (GPIOA2)
A3: MS1.8 (GPIOA3), MS2.8 (GPIOA3)
A4: MS1.9 (GPIOA4), MS2.9 (GPIOA4)
A5: MS1.10 (GPIOA5), MS2.10 (GPIOA5)
ARF: MS1.3 (AREF), MS2.3 (AREF)
CLK: MICROSD.5 (SCLK), MS1.11 (GPIOSCK), MS2.11 (GPIOSCK)
CS: CS.2, MICROSD.2 (CS)
DFU: MS1.16 (NC), MS2.16 (NC)
DI: MICROSD.3 (DATA_IN), MS1.12 (GPIOMOSI), MS2.12 (GPIOMOSI)
DO: MICROSD.7 (DATA_OUT), MS1.13 (GPIOMISO), MS2.13 (GPIOMISO)
EN: GND|EN.1, MS1.27 (EN), MS2.27 (EN)
GND: B1.-, C1.2, C2.2, C3.2, GND|EN.2, JP1.1, LED1.C, LED2.C, MICROSD.6 (VSS), MICROSD.MT1 (GND), MICROSD.MT2 (GND1), MS1.4 (GND), MS2.4 (GND), R1.2, RTC.5 (NC_2), RTC.6 (NC_3), RTC.7 (NC_4), RTC.8 (NC_5), RTC.9 (NC_6), RTC.10 (NC_7), RTC.11 (NC_8), RTC.12 (NC), RTC.13 (GND), U$1.1, U$1.2, U$2.3, U$2.4, U$3.2 (S)
unnamed: 5V.1, MS2.20 (GPIO6)
unnamed: B1.+$1 (+), RTC.14 (VBAT)
unnamed: 3V.1, MS2.19 (GPIO5)
unnamed: 5V.2, R1.1, U$3.1 (G)
unnamed: C2.1, PMOS1.G, R4.2, U$3.3 (D)
unnamed: CS.1, MS1.22 (GPIO10), MS2.22 (GPIO10)
unnamed: LED1.A, R8.1
unnamed: LED2.A, R9.1
unnamed: MS1.24 (GPIO12), MS2.24 (GPIO12), RTC_INT.1
RESET: MS1.1 (!RESET), MS2.1 (!RESET), U$1.3, U$1.4
RTC_INT: INT.1, RTC.3 (!INT/SQW), RTC_INT.2, U$2.1, U$2.2
SCL: MS1.18 (GPIOSCL), MS2.18 (GPIOSCL), R7.2, RTC.16 (SCL)
SDA: MS1.17 (GPIOSDA), MS2.17 (GPIOSDA), R6.2, RTC.15 (SDA)
VBATT: MS1.28 (VBAT), MS2.28 (VBAT)
VDD: C1.1, D1.1 (C), MICROSD.4 (VDD)

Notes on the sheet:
Decoupling
Manually Wake Up (Testing purpose_)
Manually probing headers (testing purpose)
30k
Voltage drop: 1.8V Should drive at 0.5mA
(5V - 1.7V)/0.5mA
(3.3V - 1.7V)/0.5mA

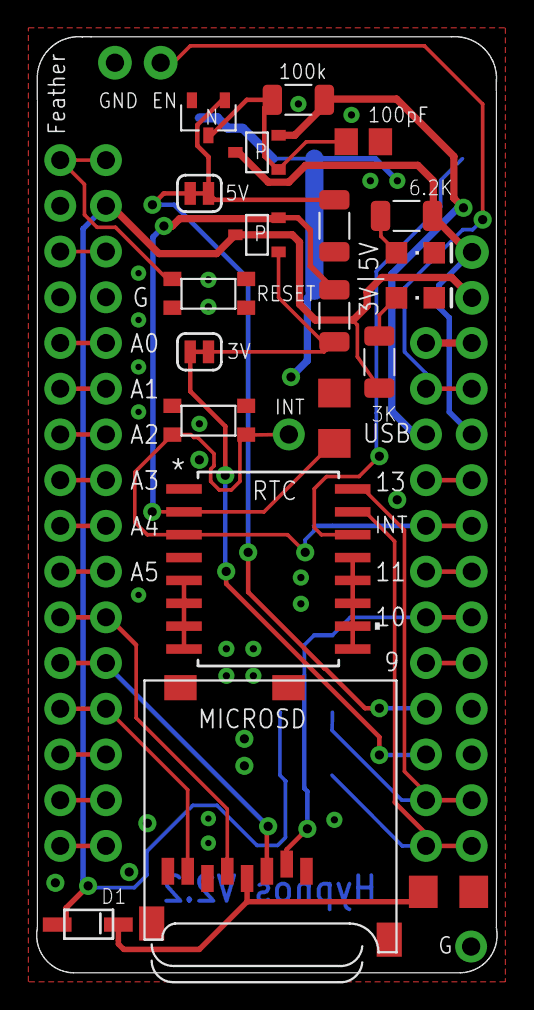
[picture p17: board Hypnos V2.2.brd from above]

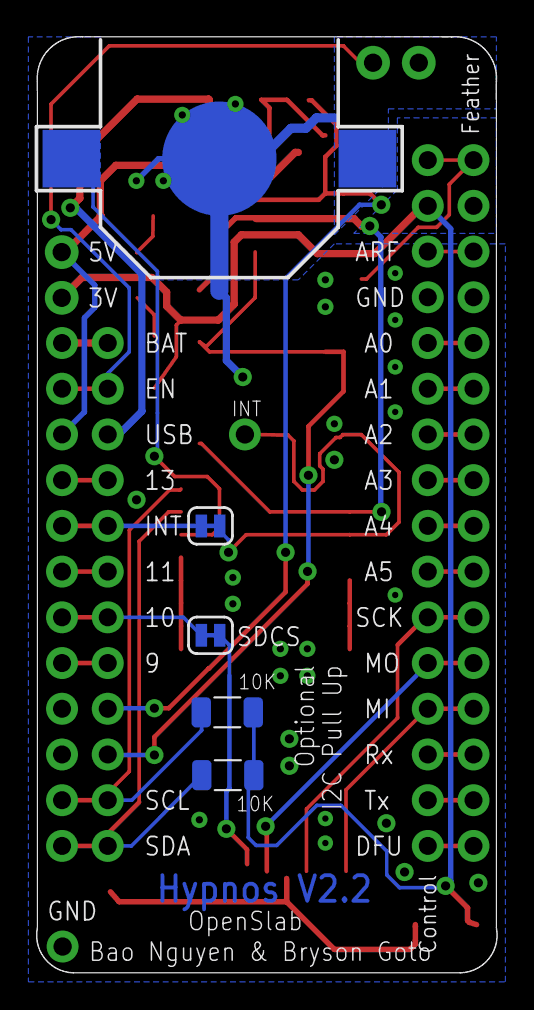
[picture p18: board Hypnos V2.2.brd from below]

Board: 2 copper layers, 25.6 x 52.0 mm, 31 parts (6 on the bottom side), 39 nets.

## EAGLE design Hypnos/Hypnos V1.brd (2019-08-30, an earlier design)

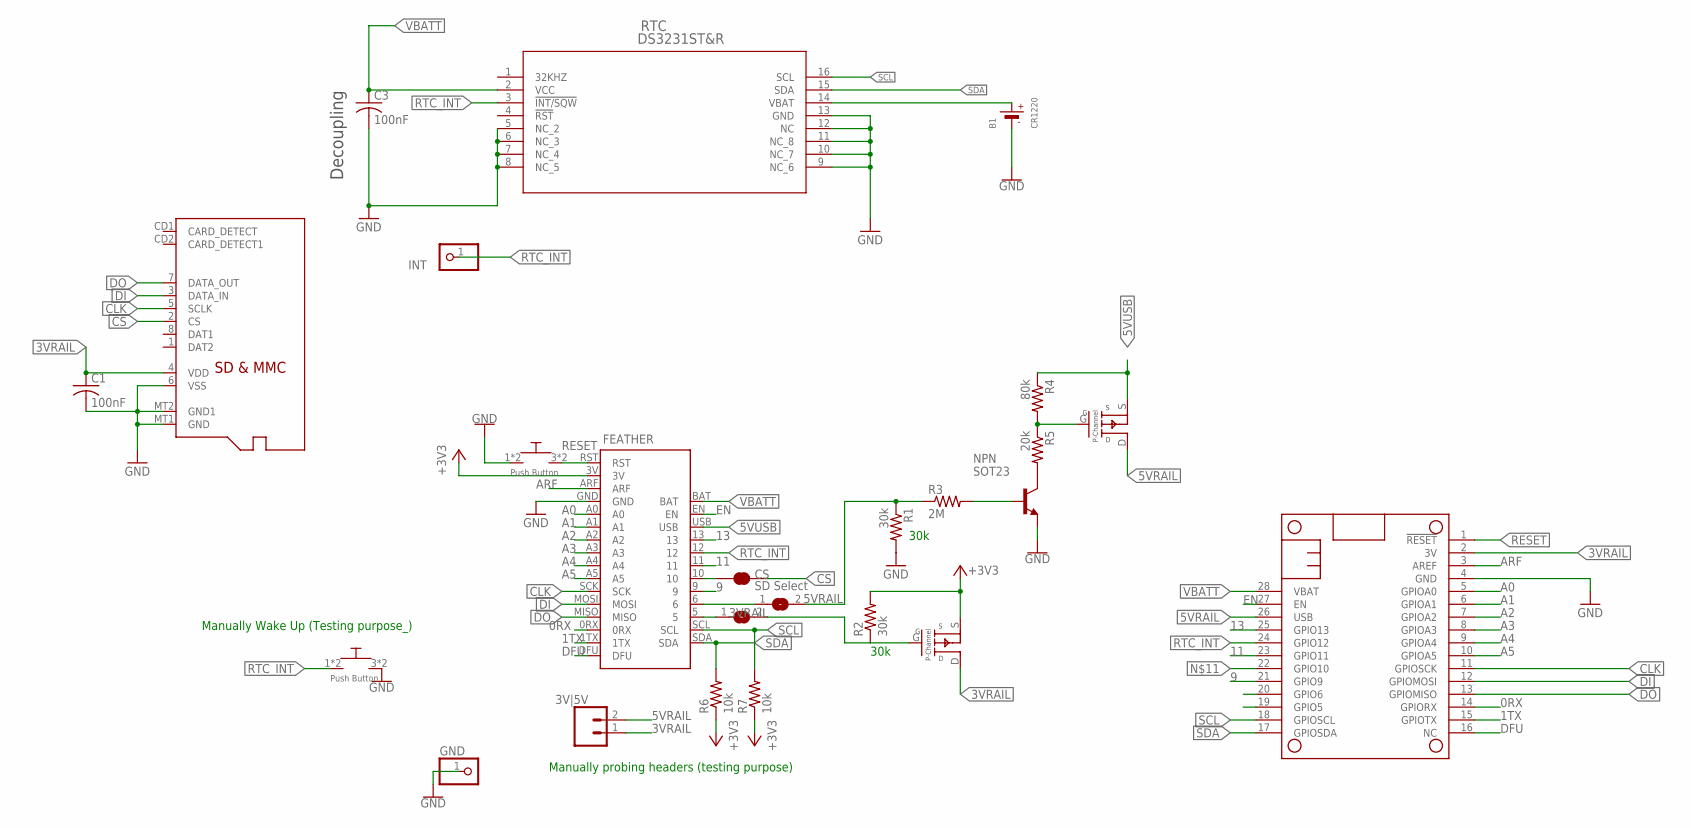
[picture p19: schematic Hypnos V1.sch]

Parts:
3VRAIL, 5VRAIL: SJ
3V|5V: CONN_021X02_NO_SILK; 1X02_NO_SILK
B1: CR1220
C1, C3: 100nF; C1206
CS: SD Select; SMT-JUMPER_2_NC_TRACE_SILK
FEATHER: BLUEFRUIT_M0; BLUEFRUIT_MO
GND: PINHD-1X1; 1X01
INT: PINHD-1X1CB; 1X01-CLEANBIG
MICROSD: MICROSD
MS1: FEATHERWING
NPN: SOT23
PMOS1, PMOS2: SSM3J3228R; SOT-23-3
R1, R2: 30k; R1206
R3: 2M; R1206
R4: 80k; R1206
R5: 20k; R1206
R6, R7: 10k; R1206
RTC: DS3231ST&R; 21-0042B_16
U$1, U$2: PUSH_BUTTON; PUSHBUTTON_SMD

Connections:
0RX: FEATHER.0RX, MS1.14 (GPIORX)
1TX: FEATHER.1TX, MS1.15 (GPIOTX)
3VRAIL: 3V|5V.1, C1.1, MICROSD.4 (VDD), MS1.2 (3V), PMOS2.D
5VRAIL: 3V|5V.2, MS1.26 (USB), PMOS1.D
5VUSB: FEATHER.USB, PMOS1.S, R4.1
9: FEATHER.9, MS1.21 (GPIO9)
11: FEATHER.11, MS1.23 (GPIO11)
13: FEATHER.13, MS1.25 (GPIO13)
+3V3: FEATHER.3V, PMOS2.S, R2.2, R6.1, R7.1
A0: FEATHER.A0, MS1.5 (GPIOA0)
A1: FEATHER.A1, MS1.6 (GPIOA1)
A2: FEATHER.A2, MS1.7 (GPIOA2)
A3: FEATHER.A3, MS1.8 (GPIOA3)
A4: FEATHER.A4, MS1.9 (GPIOA4)
A5: FEATHER.A5, MS1.10 (GPIOA5)
ARF: FEATHER.ARF, MS1.3 (AREF)
CLK: FEATHER.SCK, MICROSD.5 (SCLK), MS1.11 (GPIOSCK)
CS: CS.2, MICROSD.2 (CS)
DFU: FEATHER.DFU, MS1.16 (NC)
DI: FEATHER.MOSI, MICROSD.3 (DATA_IN), MS1.12 (GPIOMOSI)
DO: FEATHER.MISO, MICROSD.7 (DATA_OUT), MS1.13 (GPIOMISO)
EN: FEATHER.EN, MS1.27 (EN)
GND: B1.-, C1.2, C3.2, FEATHER.GND, GND.1, MICROSD.6 (VSS), MICROSD.MT1 (GND), MICROSD.MT2 (GND1), MS1.4 (GND), NPN.2 (E), R1.2, RTC.5 (NC_2), RTC.6 (NC_3), RTC.7 (NC_4), RTC.8 (NC_5), RTC.9 (NC_6), RTC.10 (NC_7), RTC.11 (NC_8), RTC.12 (NC), RTC.13 (GND), U$1.1, U$1.2, U$2.3, U$2.4
unnamed: 5VRAIL.1, FEATHER.6
unnamed: B1.+$1 (+), RTC.14 (VBAT)
unnamed: 3VRAIL.1, FEATHER.5
unnamed: 5VRAIL.2, R1.1, R3.1
unnamed: 3VRAIL.2, PMOS2.G, R2.1
unnamed: NPN.1 (B), R3.2
unnamed: NPN.3 (C), R5.2
unnamed: PMOS1.G, R4.2, R5.1
unnamed: CS.1, FEATHER.10, MS1.22 (GPIO10)
RESET: FEATHER.RST, MS1.1 (!RESET), U$1.3, U$1.4
RTC_INT: FEATHER.12, INT.1, MS1.24 (GPIO12), RTC.3 (!INT/SQW), U$2.1, U$2.2
SCL: FEATHER.SCL, MS1.18 (GPIOSCL), R7.2, RTC.16 (SCL)
SDA: FEATHER.SDA, MS1.17 (GPIOSDA), R6.2, RTC.15 (SDA)
VBATT: C3.1, FEATHER.BAT, MS1.28 (VBAT), RTC.2 (VCC)

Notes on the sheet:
Decoupling
Manually Wake Up (Testing purpose_)
Manually probing headers (testing purpose)
30k

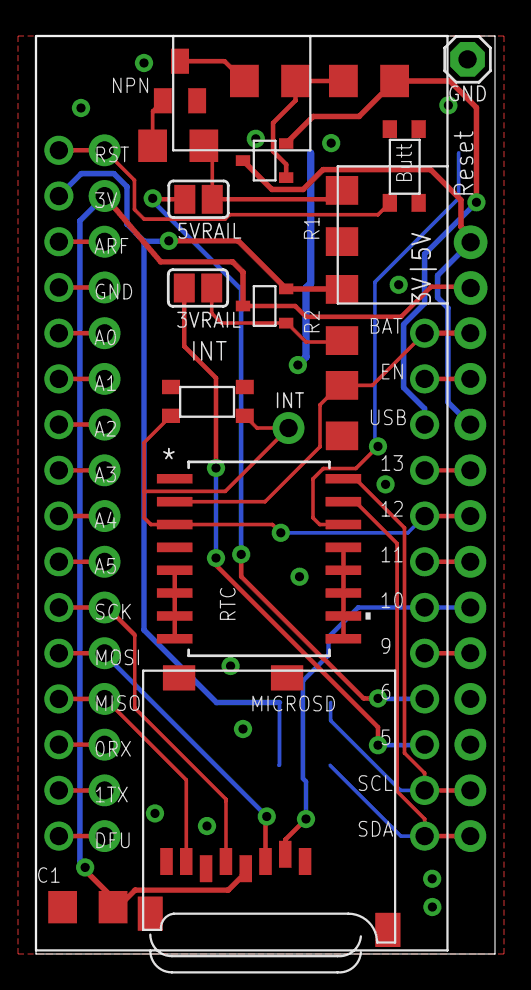
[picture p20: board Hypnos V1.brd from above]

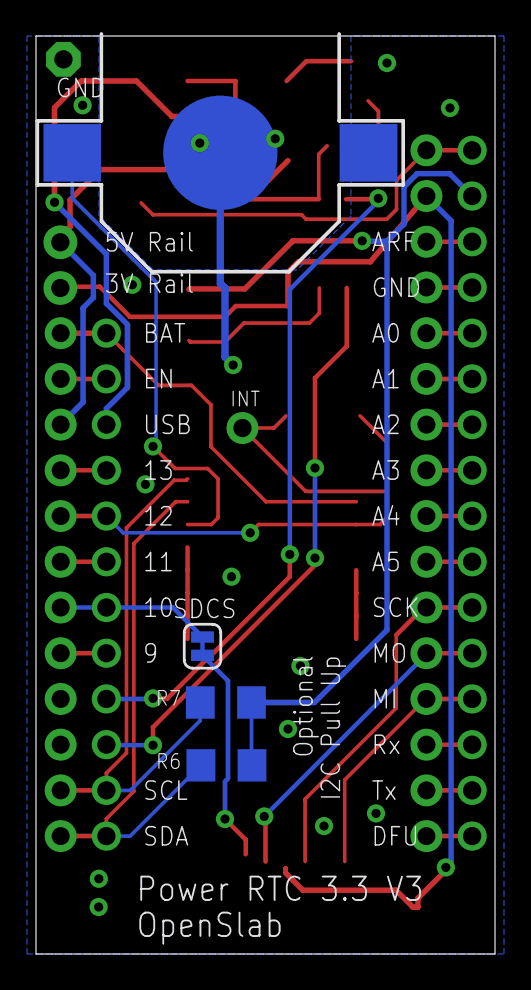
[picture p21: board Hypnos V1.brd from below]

Board: 2 copper layers, 25.5 x 51.0 mm, 25 parts (5 on the bottom side), 37 nets.

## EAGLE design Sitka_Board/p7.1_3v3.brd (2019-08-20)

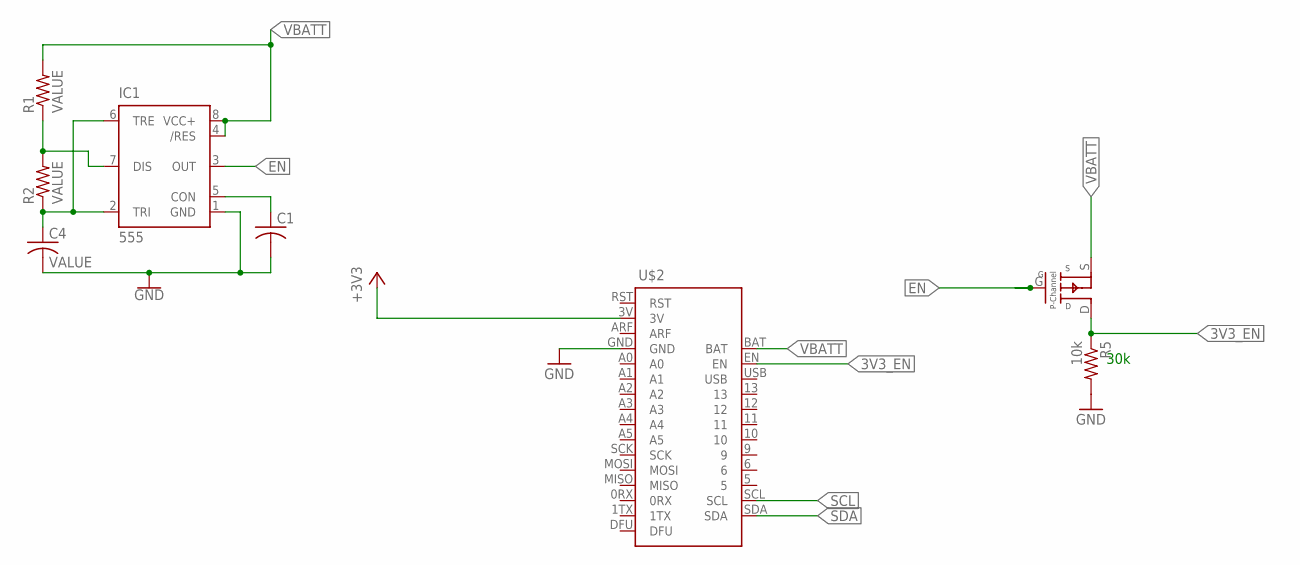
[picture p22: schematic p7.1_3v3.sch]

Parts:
C1: C-USC1206; C1206
C4: VALUE; C1206
IC1: 555; DIP08
Q2: SSM3J3228R; SOT-23-3
R1, R2: VALUE; R1206
R5: 10k; R1206
U$2: BLUEFRUIT_M0; BLUEFRUIT_MO

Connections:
3V3_EN: Q2.D, R5.1, U$2.EN
+3V3: U$2.3V
EN: IC1.3 (OUT), Q2.G
GND: C1.2, C4.2, IC1.1 (GND), R5.2, U$2.GND
unnamed: C4.1, IC1.2 (TRI), IC1.6 (TRE), R2.1
unnamed: IC1.7 (DIS), R1.1, R2.2
unnamed: C1.1, IC1.5 (CON)
SCL: U$2.SCL
SDA: U$2.SDA
VBATT: IC1.4 (/RES), IC1.8 (VCC+), Q2.S, R1.2, U$2.BAT

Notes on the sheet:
30k

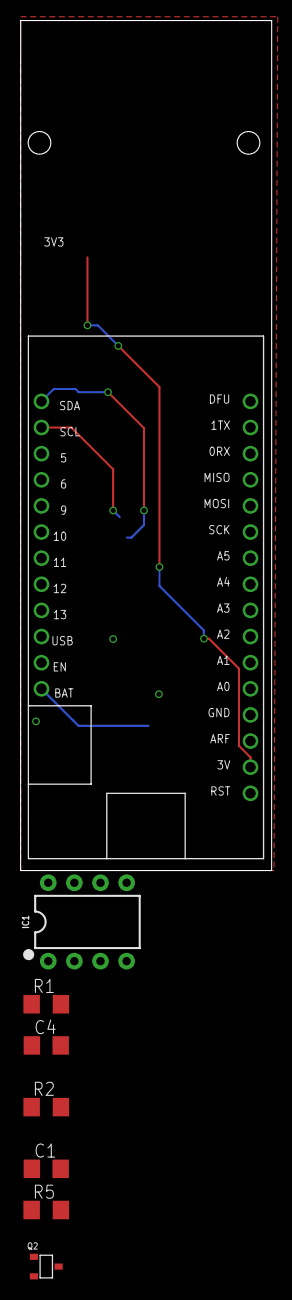
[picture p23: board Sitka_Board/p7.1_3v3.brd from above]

Board: 2 copper layers, 24.4 x 82.6 mm, 8 parts (0 on the bottom side), 7 nets.

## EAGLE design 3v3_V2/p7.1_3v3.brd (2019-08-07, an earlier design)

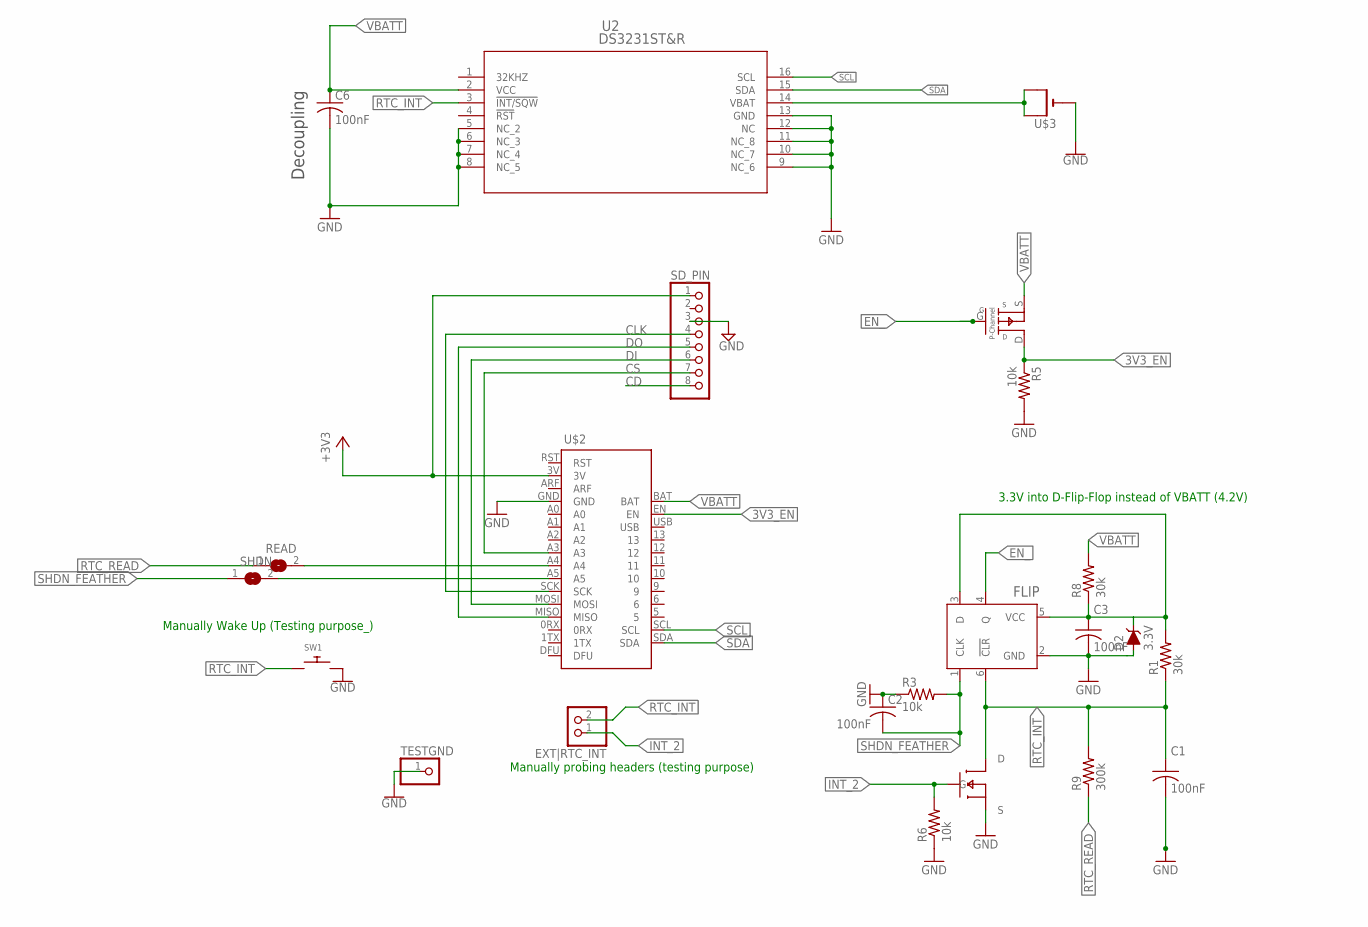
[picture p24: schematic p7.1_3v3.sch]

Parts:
C1, C2, C3, C6: 100nF; C1206
D2: 3.3V; SOD-323
EXT|RTC_INT: PINHD-1X2; 1X02
FLIP: SN74LVC1G175DBVR; DBV6
PMOS: MOSFET-SOT23F; SOT-23F
Q2: SSM3J3228R; SOT-23-3
R1, R8: 30k; R1206
R3, R5, R6: 10k; R1206
R9: 300k; R1206
READ: SJ
SD_PIN: PINHD-1X8BIG; 1X08-BIG
SHDN: SJ
SW1: SWITCH_PUSHBUTTONSOFTTOUCHSMD_SJ; PUSHBUTTON_SMD_SJ
TESTGND: PINHD-1X1; 1X01
U2: DS3231ST&R; 21-0042B_16
U$2: BLUEFRUIT_M0; BLUEFRUIT_MO
U$3: CR1220SMT; CR1220-SMD

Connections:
3V3_EN: Q2.D, R5.1, U$2.EN
+3V3: SD_PIN.1, U$2.3V
CD: SD_PIN.8
CLK: SD_PIN.4, U$2.SCK
CS: SD_PIN.7, U$2.A3
DI: SD_PIN.6, U$2.MOSI
DO: SD_PIN.5, U$2.MISO
EN_: FLIP.4 (Q), Q2.G
GND: C2.1, C3.2, C6.2, D2.A, FLIP.2 (GND), PMOS.S, R3.1, R5.2, R6.1, SD_PIN.3, SW1.P$2, TESTGND.1, U2.5 (NC_2), U2.6 (NC_3), U2.7 (NC_4), U2.8 (NC_5), U2.9 (NC_6), U2.10 (NC_7), U2.11 (NC_8), U2.12 (NC), U2.13 (GND), U$2.GND, U$3.-
INT_2: EXT|RTC_INT.1, PMOS.G, R6.2
unnamed: U2.14 (VBAT), U$3.+$1 (+), U$3.+$2 (+1)
unnamed: SHDN.2, U$2.A5
unnamed: READ.2, U$2.A4
unnamed: C3.1, D2.C, FLIP.3 (D), FLIP.5 (VCC), R1.2, R8.1
RTC_INT: C1.1, EXT|RTC_INT.2, FLIP.6 (!CLR), PMOS.D, R1.1, R9.2, SW1.P$1, U2.3 (!INT/SQW)
RTC_READ: R9.1, READ.1
SCL: U2.16 (SCL), U$2.SCL
SDA: U2.15 (SDA), U$2.SDA
SHDN_FEATHER: C2.2, FLIP.1 (CLK), R3.2, SHDN.1
VBATT: C6.1, Q2.S, R8.2, U2.2 (VCC), U$2.BAT

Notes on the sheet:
Decoupling
3.3V into D-Flip-Flop instead of VBATT (4.2V)
Manually Wake Up (Testing purpose_)
Manually probing headers (testing purpose)



Board: 2 copper layers, 24.4 x 82.6 mm, 23 parts (16 on the bottom side), 19 nets.

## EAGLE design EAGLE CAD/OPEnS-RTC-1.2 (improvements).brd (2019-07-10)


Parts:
C1: 1 nF; C0805
D1, D2, D3: DIODESOD-123; SOD-123
FET_N3, FET_N4: MOSFET-NREFLOW; SOT23
FET_P3, FET_P4: BSS84; SOT23
LED1, LED2: LEDSMT1206; 1206
R1, R3, R4, R9, R12, R13: 500; R0805
R5, R15: 50; R0805
R8, R10, R14: 10k; R0805
R11, R16: 200; R0805
SLIDE_SWITCH: SS001-S032NAPA1.2; SS001S032NAPA12
U$1, U$2: NOT_GATE; SOT753

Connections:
+3V3: R10.2, SLIDE_SWITCH.4 (N.O._2)
+4.1V: FET_P4.2 (S), U$1.5 (VCC), U$2.5 (VCC); also elsewhere on the board
ALM_READ: D3.A, R10.1; also elsewhere on the board
GND: C1.2, FET_N3.2 (S), FET_N4.2 (S), LED1.C, LED2.C, R14.2, SLIDE_SWITCH.1 (N.O._1), SLIDE_SWITCH.6 (N.C._2), U$1.3 (GND), U$2.3 (GND); also elsewhere on the board
INT+: R13.2; also elsewhere on the board
LOAD_HV: FET_P3.3 (D); also elsewhere on the board
LOAD_LV: FET_P4.3 (D); also elsewhere on the board
unnamed: R11.1, U$1.4 (OUT)
unnamed: R4.1, U$1.2 (IN)
unnamed: R1.2, U$2.4 (OUT)
unnamed: FET_N3.1 (G), R3.1, U$2.2 (IN)
unnamed: FET_N3.3 (D), R8.1, R9.2
unnamed: R5.1, SLIDE_SWITCH.5 (COM_2)
unnamed: FET_P3.1 (G), R9.1
unnamed: LED1.A, R11.2
unnamed: FET_P4.1 (G), R12.1
unnamed: D1.A, R15.1
unnamed: FET_N4.1 (G), R13.1, R14.1
unnamed: LED2.A, R16.2
OVR_READ: R5.2, R16.1; also elsewhere on the board
RTC_ALM: D2.C, D3.C; also elsewhere on the board
SHDN: R15.2, SLIDE_SWITCH.8 (N.C._3); also elsewhere on the board
SHDN/1.1D: SLIDE_SWITCH.7 (COM_3)
VCC_HV: FET_P3.2 (S), R8.2; also elsewhere on the board
V_LATCH: C1.1, D1.C, D2.A, FET_N4.3 (D), R1.1, R4.2, R12.2, SLIDE_SWITCH.2 (COM_1); also elsewhere on the board
V_LATCH1: R3.2

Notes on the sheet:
James Yang
OPEnS Lab OSU
Low-pass
set value based on expected noise


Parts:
C6: 100nF; C0805
D4: DIODESOD-123; SOD-123
FEATHER: BLUEFRUIT_M0; BLUEFRUIT_MO
HV: JST_2PIN-SMT; JST-PH-2-SMT
HV_IN: PJ-028-SMT-TR; CUI_PJ-028-SMT-TR
HV_SW: JST_2PIN-SMT; JST-PH-2-SMT
INT+: JST_2PIN-SMT; JST-PH-2-SMT
LV: JST_2PIN-SMT; JST-PH-2-SMT
LV_IN: JST_2PIN-SMT; JST-PH-2-SMT
LV_SW: JST_2PIN-SMT; JST-PH-2-SMT
SD_PIN: PINHD-1X8BIG; 1X08-BIG
SJ1, SJ2, SJ3: SJ
TEST1, TEST2, TEST3, TEST4, TEST5, TEST6: PINHD-1X1; 1X01
U2: DS3231ST&R; 21-0042B_16
U$3: CR1220SMT; CR1220-SMD

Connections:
+4.1V: LV.1 (2), LV_IN.1 (2); also elsewhere on the board
ALM_READ: SJ2.2; also elsewhere on the board
CD: SD_PIN.8
CLK: FEATHER.SCK, SD_PIN.4
CS: FEATHER.A3, SD_PIN.7
DI: FEATHER.MOSI, SD_PIN.6
DO: FEATHER.MISO, SD_PIN.5
GND: C6.2, FEATHER.GND, HV.2 (1), HV_IN.2, HV_IN.3, HV_IN.3.1 (3), HV_SW.2 (1), INT+.2 (1), LV.2 (1), LV_IN.2 (1), LV_SW.2 (1), SD_PIN.3, TEST6.1, U2.5 (NC_2), U2.6 (NC_3), U2.7 (NC_4), U2.8 (NC_5), U2.9 (NC_6), U2.10 (NC_7), U2.11 (NC_8), U2.12 (NC), U2.13 (GND), U$3.-; also elsewhere on the board
INT+: INT+.1 (2); also elsewhere on the board
LOAD_HV: HV_SW.1 (2), TEST4.1; also elsewhere on the board
LOAD_LV: C6.1, D4.A, FEATHER.BAT, LV_SW.1 (2), TEST5.1, U2.2 (VCC); also elsewhere on the board
unnamed: FEATHER.A4, SJ2.1
unnamed: FEATHER.A5, SJ1.2
unnamed: FEATHER.9, SJ3.2
OVR_READ: SJ3.1; also elsewhere on the board
RTC_ALM: TEST2.1, U2.3 (!INT/SQW); also elsewhere on the board
SCL: U2.16 (SCL)
SDA: U2.15 (SDA)
SHDN: SJ1.1; also elsewhere on the board
VCC: FEATHER.3V, SD_PIN.1
VCC_HV: HV.1 (2), HV_IN.1; also elsewhere on the board
V_BACKUP: D4.C, TEST1.1, U2.14 (VBAT), U$3.+$1 (+), U$3.+$2 (+1)
V_LATCH: TEST3.1; also elsewhere on the board

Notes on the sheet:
James Yang OPEnS Lab OSU
Decoupling

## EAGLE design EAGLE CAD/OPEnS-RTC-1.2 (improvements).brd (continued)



Board: 2 copper layers, 24.0 x 108.0 mm, 48 parts (26 on the bottom side), 33 nets.

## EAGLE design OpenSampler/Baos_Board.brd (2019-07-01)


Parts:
D1, D2, D3: DIODESOD-123; SOD-123
FET_N1, FET_N2, FET_N4: MOSFET-NREFLOW; SOT23
FET_P1, FET_P2, FET_P4: BSS84; SOT23
LED1: LEDSMT1206; 1206
R1, R2, R4, R6, R12, R13: 500; R0805
R3, R10: 30k; R0805
R7: 4.7k; R0805
R11: 1k; R0805
R14: 10k; R0805
R15: 50; R0805

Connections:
+3V3: R10.2; also elsewhere on the board
+12V: FET_P1.2 (S), FET_P2.2 (S), FET_P4.2 (S), R3.2; also elsewhere on the board
ALM_READ: D3.A, R10.1; also elsewhere on the board
GND: FET_N1.2 (S), FET_N2.2 (S), FET_N4.2 (S), LED1.C, R14.2; also elsewhere on the board
INT+: R13.2
unnamed: FET_P1.3 (D), R2.2, R11.1
unnamed: FET_N1.3 (D), R1.1
unnamed: FET_N1.1 (G), FET_P1.1 (G), R4.1
unnamed: FET_N2.1 (G), FET_P2.1 (G), R1.2, R2.1
unnamed: FET_P2.3 (D), R7.2
unnamed: FET_N2.3 (D), R6.1
unnamed: LED1.A, R11.2
unnamed: FET_P4.1 (G), R12.1
unnamed: D1.A, R15.1
unnamed: FET_N4.1 (G), R13.1, R14.1
REGULATOR: FET_P4.3 (D); also elsewhere on the board
RTC_ALM: D2.C, D3.C; also elsewhere on the board
SHDN: R15.2; also elsewhere on the board
V_LATCH: D1.C, D2.A, FET_N4.3 (D), R3.1, R4.2, R6.2, R7.1, R12.2; also elsewhere on the board

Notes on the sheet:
James Yang, Bao Nguyen
OPEnS Lab OSU


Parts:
C2, C6: 100nF; C0805
FRAM: FRAM; FPT-8P-M02
JP1, JP2: PINHD-1X6; 1X06
JP3: PINHD-1X3; 1X03
RTC: DS3231ST&R; 21-0042B_16
TEST6: PINHD-1X1; 1X01
U$1: CR1220SMT; CR1220-SMD

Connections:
+3V3: C2.1, FRAM.8 (VDD), JP1.4, JP2.3; also elsewhere on the board
+12V: JP1.2; also elsewhere on the board
ALM_READ: JP2.4; also elsewhere on the board
GND: C2.2, C6.2, FRAM.4 (VSS), JP1.1, RTC.5 (NC_2), RTC.6 (NC_3), RTC.7 (NC_4), RTC.8 (NC_5), RTC.9 (NC_6), RTC.10 (NC_7), RTC.11 (NC_8), RTC.12 (NC), RTC.13 (GND), TEST6.1, U$1.-; also elsewhere on the board
LOAD_LV: C6.1, JP3.3, RTC.2 (VCC)
unnamed: RTC.14 (VBAT), U$1.+$1 (+), U$1.+$2 (+1)
REGULATOR: JP1.6; also elsewhere on the board
RTC_ALM: JP3.1, RTC.3 (!INT/SQW); also elsewhere on the board
SCL: FRAM.6 (SCL), JP2.2, RTC.16 (SCL)
SDA: FRAM.5 (SDA), JP2.1, RTC.15 (SDA)
SHDN: JP2.5; also elsewhere on the board
V_LATCH: JP1.5, JP3.2; also elsewhere on the board

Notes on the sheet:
James Yang, Bao Nguyen OPEnS Lab OSU



Board: 2 copper layers, 57.0 x 26.1 mm, 31 parts (5 on the bottom side), 22 nets.

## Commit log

2019-01-03 Changed names to match first release.
    This is now version 1.0.0 of OPEnS-Power, and was previously named Power7.1
    [OPEnS-Power-1.0.0.brd, OPEnS-Power-1.0.0.sch]
2019-04-15 Add files via upload
    Added 3v3 Board
    [p7.1_3v3.brd, p7.1_3v3.sch]
2019-05-10 Fixed ground issue
    GND pin
2019-08-30 Final update for 3.3V prototype
    [Part.xlsx, p7.1_3v3 - Adafruit Battery.brd, p7.1_3v3 - Adafruit Battery.sch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]
2019-08-30 Updated Bill of Material
    [Bill of Materials.xlsx]
2019-08-30 Archiving older versions
    Short info is included in Reason for archiving.txt
    [BOM Baos_Board.xlsx, Baos_Board.brd, Baos_Board.sch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]
2019-08-30 Added 12V version with RTC
    This board is currently tested on the eDNA
    Added eDNA eagle lib
    Archived older versions
    [BOM 3.3V V2 Powerboard.xlsx, BOM OPEnS Power 7.2.xlsx, Bill of Materials.xlsx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]
2019-08-31 Added 3 Volt V3 images
2019-08-31 Add 12v 7.2 images
2019-09-04 Added readme for 12V 7.2
2019-09-04 Update BOM OPEnS Power 7.2.xlsx
    Add cost and remove overlap listing
    [BOM OPEnS Power 7.2.xlsx]
2019-10-03 Remove 12V OpenSpower
    Remove 12V version to other repo for easier version control
    [BOM OPEnS Power 7.2.xlsx, Bill of Materials.xlsx, Hypnos V1.brd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]
2019-10-03 Testing for Version V2
    Update from Version 1:
    * 2 LEDs with current limiting resistors
    * RTC is now powered from 3V3 instead of Vbat (using power from Vbat turns on Feather Battery Charger LED)
    * Pull up resistor for SD chip select just like adalogger
    * Rounded PCB corner
    * Move the reset button to the middle of the board - mechanically more stable
    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
    [Bill of Materials - Hypnos V2.xlsx, Bill of Materials.xlsx, Hypnos V2.brd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]
2019-10-08 Schematic Change for Hypnos V2
    Update Hypnos V2
    * Change from BJT to Logic MOSFET. Using BJT require current limiting resistor and also involve more calculation.
    * Remove R5 to simplify the circuit
    * Increase trace width for all power rail
    * Change resistors footprint to get more space and better indication for solder orientation
    Update eDNA.lbr
    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
    [Bill of Materials - Hypnos V2.xlsx, Hypnos V2.brd, Hypnos V2.sch]
2019-10-15 Update Bill of Materials - Hypnos V2.xlsx
    Update the right part for 100k ohm resistor
    [Bill of Materials - Hypnos V2.xlsx]
2019-10-22 N-Mos Bug FIx
    Wrong footprint layout - Drain and Source was switched
    [Hypnos V2.brd, Hypnos V2.sch]
2019-11-01 Hypnos V3 Beta
    Hypnos V3 PCBs design is finalized. Sent out for fabrication for further testing.
    [Bill of Materials - Hypnos V3.xlsx, Hypnos V3.brd, Hypnos V3.sch]
2019-11-26 Update Bill of Material Hypnos V2
    Correction to 100pF Part ID Digikey
    [Bill of Materials - Hypnos V2.xlsx]
2020-01-27 Added Diode
    Hardware fix for uSD card current leak. Added diode with low current leakage to prevent current from SPI pins going back to 3VRAIL.
    [Bill of Materials - Hypnos V2.xlsx, Hypnos V2.brd, Hypnos V2.sch]
2020-01-27 Update Bill of Materials - Hypnos V2.xlsx
    Remove 82k resistor. New schematic does not use the same part.
    [Bill of Materials - Hypnos V2.xlsx]
2020-01-28 Hypnos V3 hardware fix
    Added diode to Hypnos V3 to minimize leaking current from uSD card to 3VRAIL.
    Add pdf for schematic Hypnos V2 + Hypnos V3
    Updated bill of material to Hypnos V3
    [Bill of Materials - Hypnos V2.xlsx, Bill of Materials - Hypnos V3.xlsx, Hypnos V3.brd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]
2020-03-24 I2C line connected to 3.3Rail
    Remoce I2C line from 3.3Rail reduce power going back to sersor when they are turned off.
    [Hypnos V2_2.24.brd, Hypnos V2_2.24.sch]
2020-03-31 Add files via upload
    I2C line connected to 3.3Rail
    [Hypnos V3.1.brd, Hypnos V3.1.sch]
2020-03-31 I2C line connected to 3.3Rail
2020-04-09 Renamed for convention
    [Hypnos V2.1.brd, Hypnos V2.1.sch]
2020-04-10 Update 3V trace for Hypnos V3
    Route missing trace for V3
    Add bStop layer for V2
    Clean up some note on schematic V2 and V3
    [Bill of Materials - Hypnos V2.1.xlsx, Bill of Materials - Hypnos V3.1.xlsx, Hypnos V2.1.brd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]
2020-04-13 Updated 3V Trace for Hypnos V3
2020-04-20 Update Hypnos V3.1.brd
    [Hypnos V3.1.brd]
2020-04-22 Update Bill of Materials - Hypnos V3.1.xlsx
    [Bill of Materials - Hypnos V3.1.xlsx]
2020-05-10 Folder prep for release
    Updated
    +Readme
    +Folder name
    +Gerber files
    [Bill of Materials - Hypnos V2.1.xlsx, Bill of Materials - Hypnos V3.1.xlsx, Hypnos V2.1.brd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]
2020-05-24 Update BOM
    [Bill of Materials - Hypnos V2.1.xlsx, Bill of Materials - Hypnos V3.1.xlsx]
2020-07-03 Hypnos 2.2 and 3.2
    +Change solder bridge to always connected pad
    +Remove solder bridge for D1 diode
    [Bill of Materials - Hypnos V2.2.xlsx, Bill of Materials - Hypnos V3.2.xlsx, Hypnos V2.2.brd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]
2020-07-18 Added board + schematic PDFs
2020-08-03 Fixed equation for 10k resistor
    [Bill of Materials - Hypnos V3.2.xlsx]
2021-05-12 Updated documentation (BOM, components in schematics, pick-n-place file)
    [Bill of Materials - Hypnos V3.2.xlsx, Hypnos V3.2.brd, Hypnos V3.2.sch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]
2021-05-12 HardwareX documentation revision
    [Hypnos V3.2.brd, Hypnos V3.2.sch, Hypnos V3.2_centroid.csv]
2021-05-12 Update RTC documentation
    [Hypnos V3.2.brd, Hypnos V3.2.sch]
2021-07-27 Hypnos V3.3 Update
    Changed SD pin from GPIO10 to GPIO9 and removed extra capacitors from design
    [Bill of Materials - Hypnos V3.2.xlsx, Bill of Materials - Hypnos V3.3.xlsx, HypnosV3.3.brd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]
2021-07-28 Hypnos V3.3 Update
    Switched SD pin from pin 9 to pin 11 due to Feather pin issues, updated BOM with in-stock parts from Digikey
    [Bill of Materials - Hypnos V3.3.xlsx, HypnosV3.3.brd, HypnosV3.3.sch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]
2021-09-24 Update HypnosV3.3_Sch.pdf
    Fixed flipped schematic
2023-07-27 Added 3.2 for reference
    [Bill of Materials - Hypnos V3.2.xlsx, Hypnos V3.2.brd, Hypnos V3.2.sch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]

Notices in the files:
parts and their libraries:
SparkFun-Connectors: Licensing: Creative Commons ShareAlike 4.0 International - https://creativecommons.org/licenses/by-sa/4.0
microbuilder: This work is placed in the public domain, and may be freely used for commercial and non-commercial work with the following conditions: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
